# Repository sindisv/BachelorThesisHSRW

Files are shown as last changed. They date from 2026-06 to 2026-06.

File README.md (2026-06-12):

Thesis: Design and Development of a Cost-Effective Multi-Sensor Wearable System for Real-Time Biomechanical Analysis in Boxing

This repository contains the files and assets for the thesis. The top-level folders hold CAD models, electrical schematics, firmware, training data and a packaged software application. The application distributed with this repository is provided as a zip file.

Folder summary

* Software Arduino Sketches: Arduino/embedded firmware source code for the different device variants (sketch\_device1..4). Use the Arduino IDE or compatible toolchain to open and upload the .ino sketches to the target boards.
* Software Application: Packaged application for the project. The file My Application.zip contains the compiled application or installers/resources. Unzip the archive (for example with Explorer, 7-Zip, or unzip) and follow the included instructions or run the extracted executable where appropriate.
* CAD Files Fusion360: Fusion360 3D model files, STEP files and drawing exports. Subfolders separate 3D files and drawing sheets for each device/unit. These are used for enclosure and mechanical design.
* Electrical Schematics KiCad: KiCad schematic files for each device (Device 1..4) and custom symbols. Open these with KiCad to view or modify the electrical designs and generate PCBs.
* Training Sessions CSV and XLSX Files: CSV & XLSX datasets collected during training sessions. These contain recorded sensor data for specific motions and can be used for analysis, training models or evaluation.
* Software Machine Learning: python scripts for running, training and processing the machine learning.

Notes

* The repository does not currently include an installed application — the application is provided zipped under Software Application/My Application.zip. Extract that archive to access the application files.
* Inspect each folder for README or instruction files specific to that component (for example CAD export notes or KiCad project details).

Important files and expanded per-folder details

1. Software Arduino Sketches
* sketch\_device1/sketch\_device1.ino — firmware for device 1
* sketch\_device2/sketch\_device2.ino — firmware for device 2
* sketch\_device3/sketch\_device3.ino — firmware for device 3
* sketch\_device4/sketch\_device4.ino — firmware for device 4
Notes: open the appropriate .ino in the Arduino IDE or PlatformIO. Check board and library requirements in the top comments of each sketch (if present) before uploading.
2. Software Application

* My Application.zip (located in Software Application/) — packaged application bundle. Extract to view installers, binaries or resource files.

3. CAD Files Fusion360
* 3D Files Fusion360/ (contains .step STEP files for enclosures, batteries, PCB models and assembly files)
* Drawings Fusion360/ (contains .dwg and .pdf drawing exports for manufacturing and assembly)
Examples: "Enclosure Unit 1.step", "Assembly Unit 1.step", and the exported PDF drawings such as "Assembly Drawing and Parts List Unit 1.pdf".
Notes: STEP files can be opened in Fusion360, FreeCAD or other CAD tools. DWG files require a CAD viewer that supports AutoCAD formats.

4. Electrical Schematics KiCad
* Circuit Device 1.kicad\_sch
* Circuit Device 2.kicad\_sch
* Circuit Device 3 and Device 4.kicad\_sch
* XIAO\_Series\_SCH\_Symbols/.../Seeed\_Studio\_XIAO\_Series.kicad\_sym (custom symbols)
Notes: Open these in KiCad to inspect or export BOM/PCB layouts. Be aware of the KiCad version used to create the project if you encounter compatibility warnings.

5. Training Sessions CSV Files
* Training Sessions CSV Files/Session 2 (Specific Motions)/Device1.csv
* Device1Uppercut.csv, Device1hookfront.csv, Device3Jab.csv, Device3uppercut.csv, Boxinghookdevice3.csv
Notes: These CSV files contain recorded sensor traces from devices during motion sessions. They can be loaded into Python, MATLAB, or Excel for analysis and model training.

6. Software Machine Learning
There is a dedicated Machine Learning workspace under "Software Machine Learning/Software Machine Learning" and processed ML outputs under "Training Sessions CSV and XLSX Files/ml_complete". This area contains scripts to label data, extract features, train classifiers and produce evaluation outputs used in the thesis.
Important scripts (Software Machine Learning/Software Machine Learning):
 - label_boxing_data.py — helpers for labeling events/windows in raw sensor traces
 - preprocess.py — feature extraction and dataset assembly (produces ml_data/features_all.csv)
 - train_model.py — training pipeline: trains multiple classifiers, evaluates with cross-validation, generates plots and saves the best model
 - quick_analysis.py — small exploratory analysis and plotting utilities
 - boxing_analysis_complete6.py — more comprehensive analysis script used for experiments

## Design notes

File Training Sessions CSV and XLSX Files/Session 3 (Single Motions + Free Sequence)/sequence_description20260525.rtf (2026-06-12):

All sequences in orthodox stance (left side forward)

Sensor setup:
——————————

D1: left ankle
D2: right ankle
D3: left wrist
D4 right wrist

Sequences:
——————————

1a) Jabs (left arm straight punch)
1b) Cross (right arm straight punch)
1c) left hook
1d) right hook
1e) left uppercut
1f) right uppercut
— all in air, no impact on punching bag

2a) -2f) as 1), with impact on punching bag

3a) low kick left
3b) low kick right
3c) mid kick left
3d) mid kick right
3e) high kick left
3f) high kick right

— all with impact on punching bag

4a) front kick left
4b) front kick right
4c) side kick left
4d) side kick right
— all with impact on punching bag

5) validation round (free sequence, all with impact on punching bag

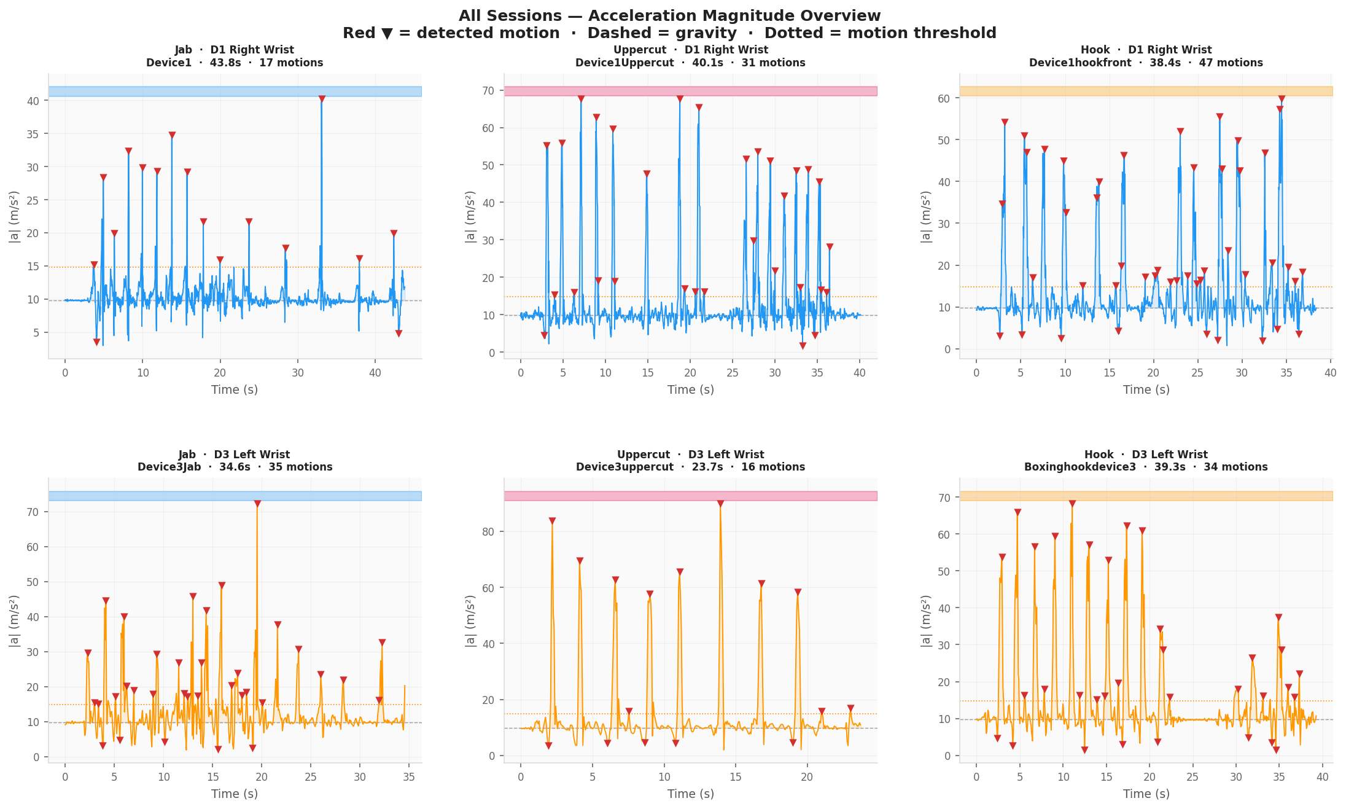
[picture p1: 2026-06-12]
Training Sessions CSV and XLSX Files/Session 2 (Specific Motions)/session2plots/overview_all_sessions.png

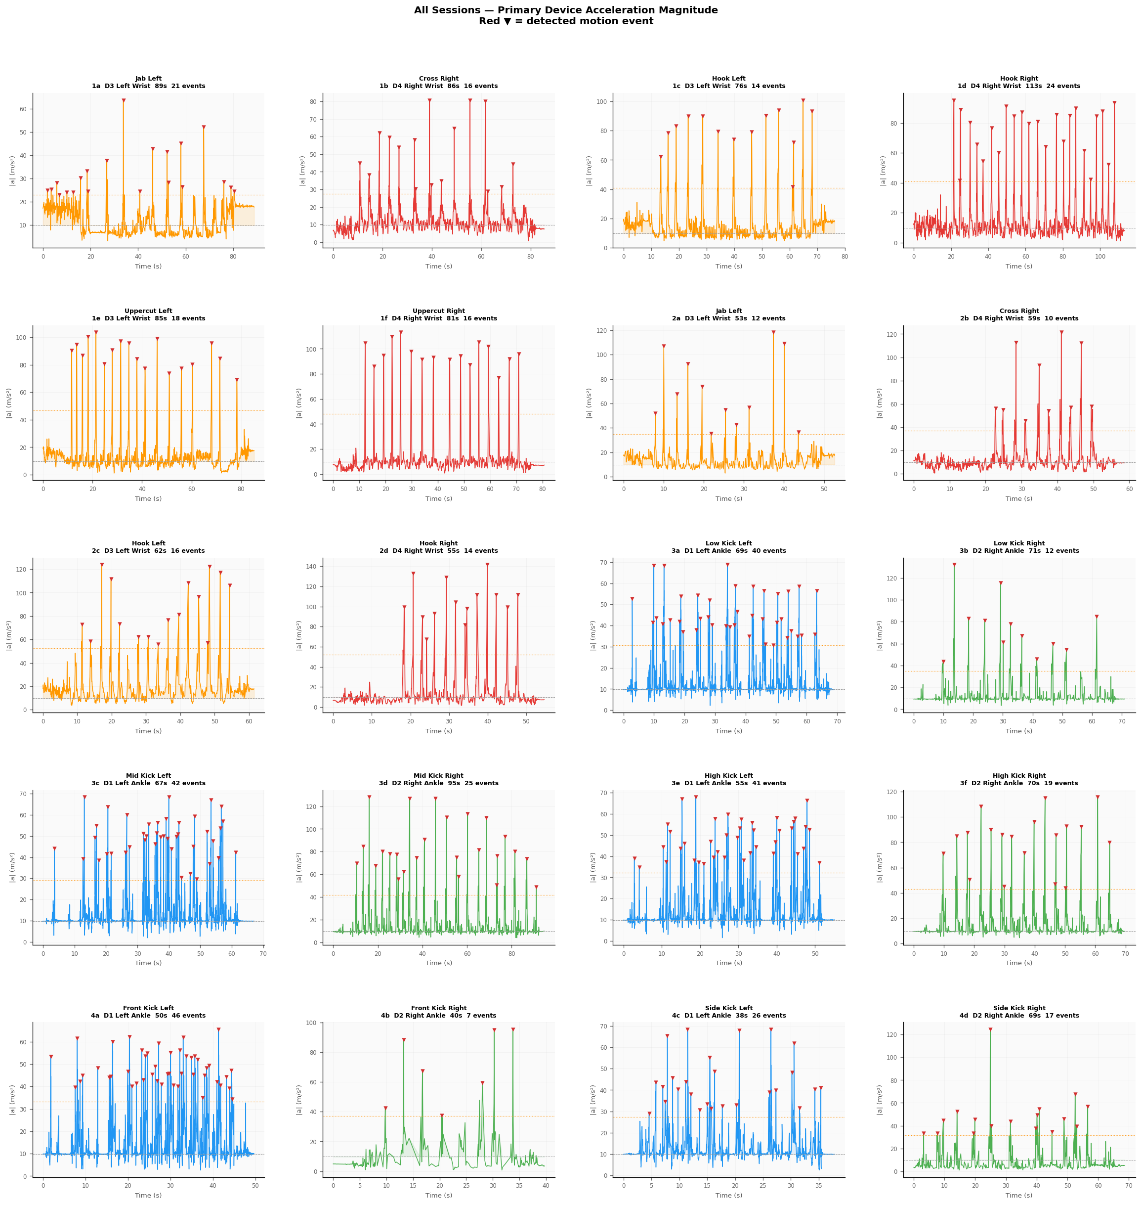
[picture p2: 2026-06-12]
Training Sessions CSV and XLSX Files/plots_complete/overview_all_sessions.png

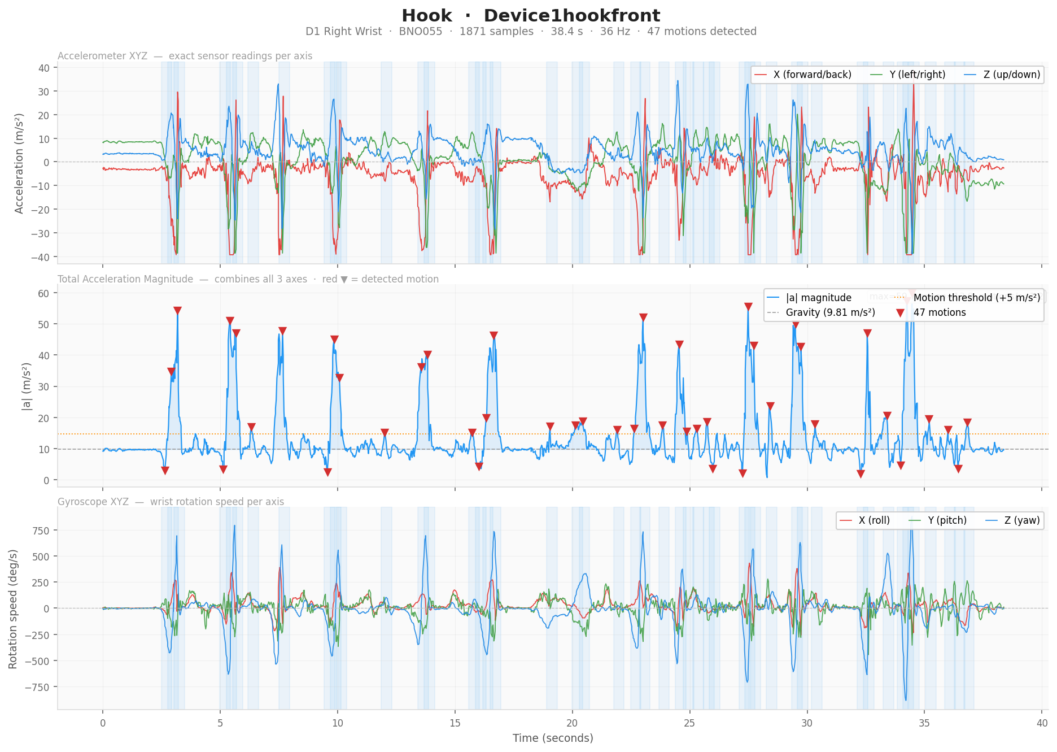
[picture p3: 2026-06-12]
Training Sessions CSV and XLSX Files/Session 2 (Specific Motions)/session2plots/Device1hookfront_analysis.png

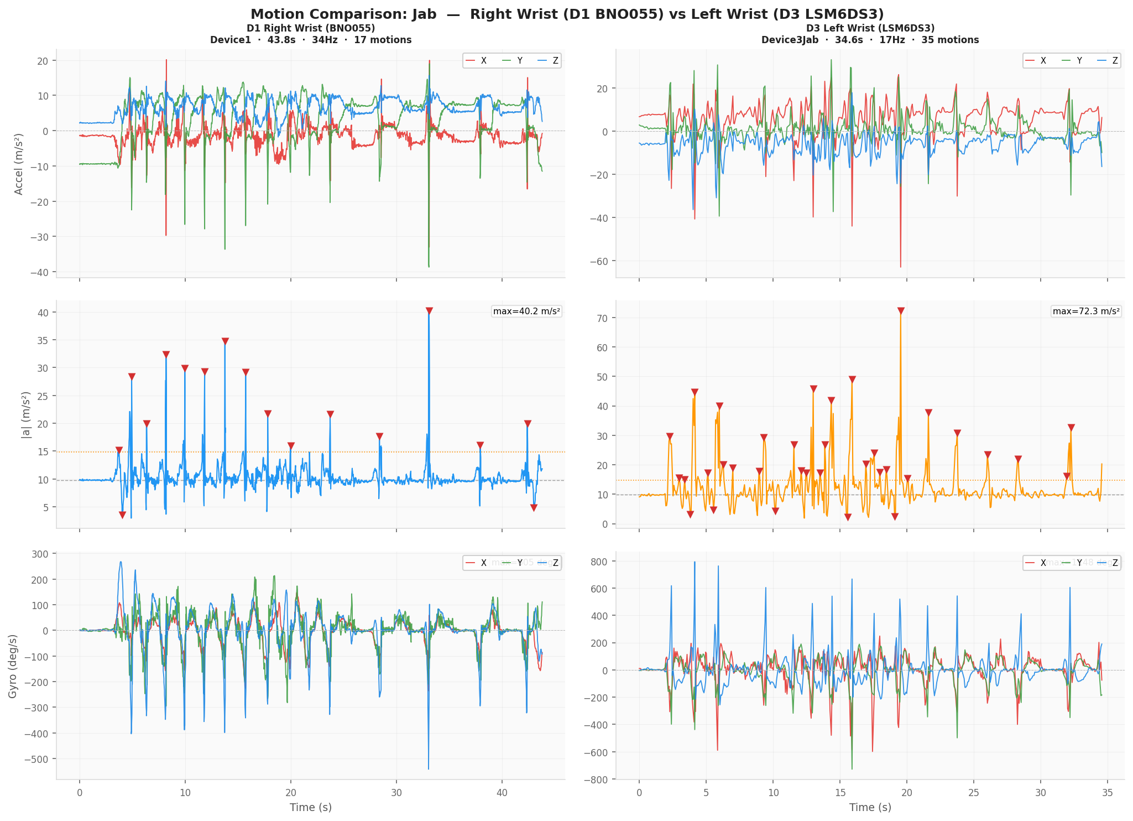
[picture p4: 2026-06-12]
Training Sessions CSV and XLSX Files/Session 2 (Specific Motions)/session2plots/comparisonofjabdevice1device3.png

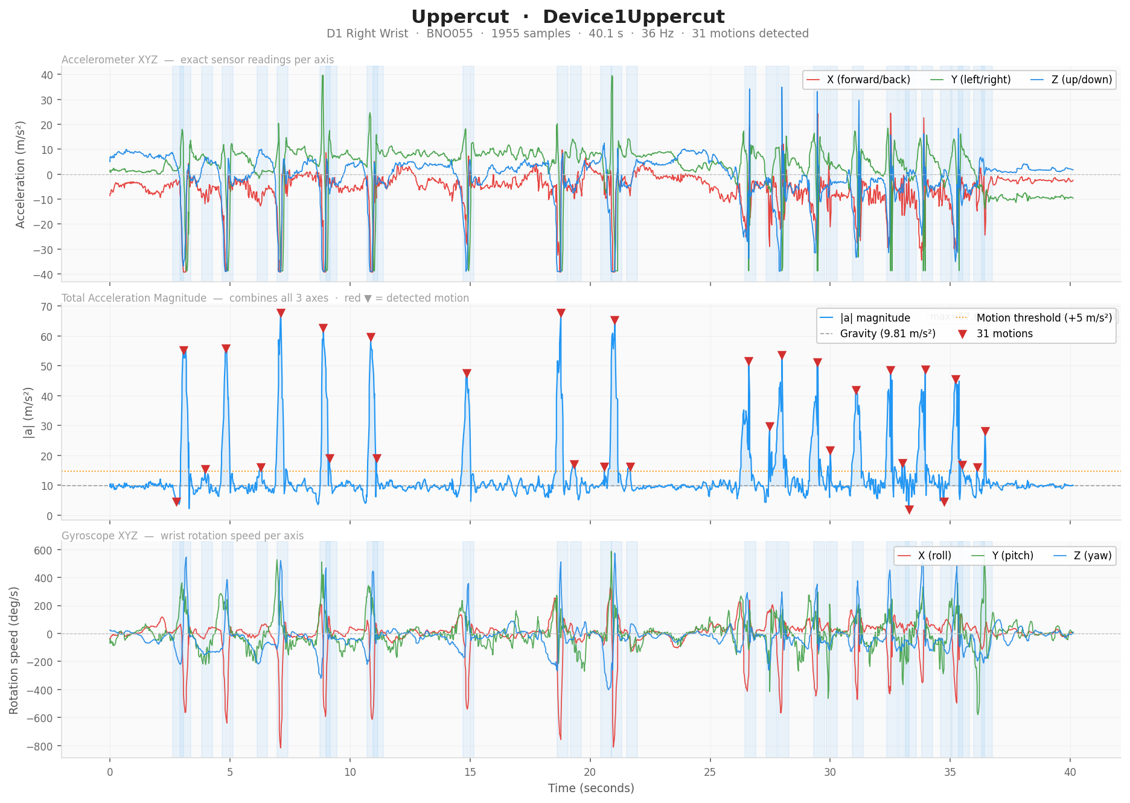
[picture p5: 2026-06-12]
Training Sessions CSV and XLSX Files/Session 2 (Specific Motions)/session2plots/Device1Uppercut_analysis.png

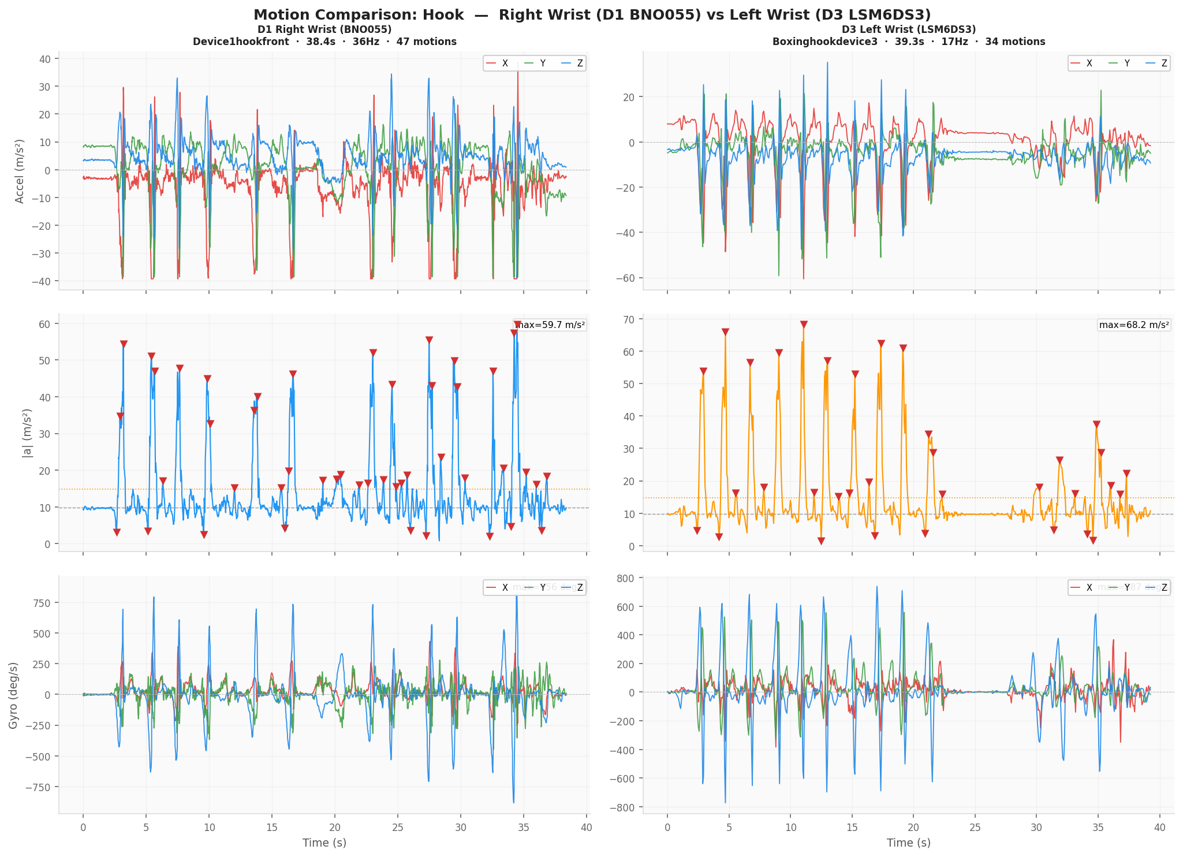
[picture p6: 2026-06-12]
Training Sessions CSV and XLSX Files/Session 2 (Specific Motions)/session2plots/compare_Hook.png

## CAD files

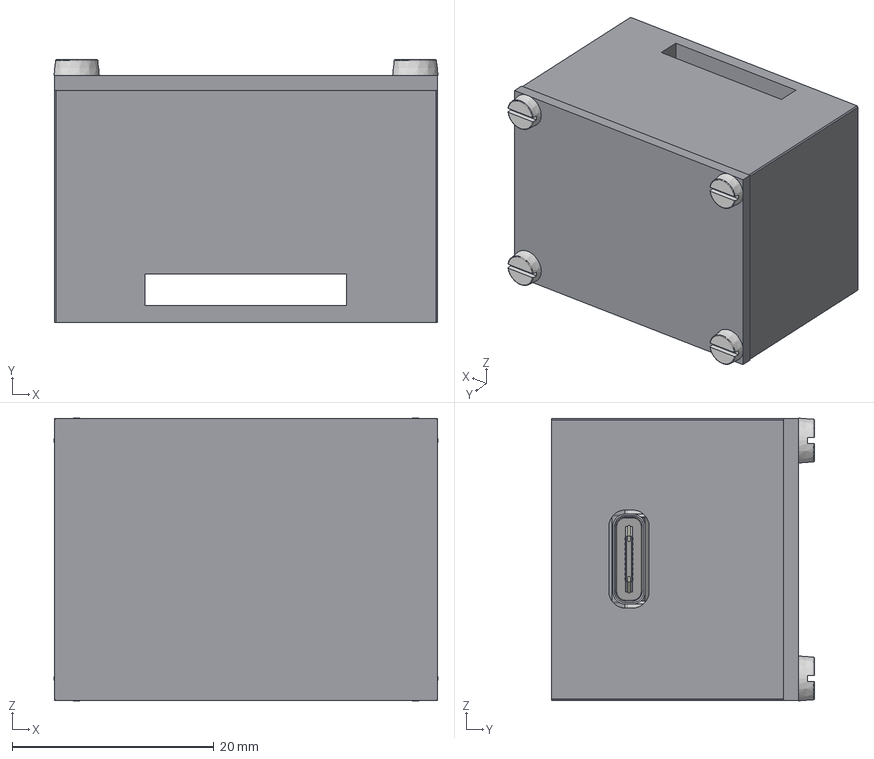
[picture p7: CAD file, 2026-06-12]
CAD Files Fusion360/3D Files Fusion360/Assemblies of the Units/Assembly Units 3 & 4.step
38.1 x 26.1 x 28.1 mm
BOSS-EXTRUDE14_8_
BOSS-EXTRUDE7_4_
BOSS-EXTRUDE7_3_
BOSS-EXTRUDE14_4_
BOSS-EXTRUDE14_2_
BOSS-EXTRUDE14_11_
BOSS-EXTRUDE7_7_
BOSS-EXTRUDE14_9_
BOSS-EXTRUDE14_3_
BOSS-EXTRUDE14_7_
MIRROR2
BOSS-EXTRUDE14_5_
BOSS-EXTRUDE14_12_
BOSS-EXTRUDE7_8_
BOSS-EXTRUDE7_1_
BOSS-EXTRUDE14_10_
BOSS-EXTRUDE7_9_
BOSS-EXTRUDE14_6_
BOSS-EXTRUDE14_1_
BOSS-EXTRUDE7_6_
BOSS-EXTRUDE7_2_
CUT-EXTRUDE5
BOSS-EXTRUDE7_5_
Shield
Pins
LiPo Battery 200 mAh
Enclosure Unit 3, 4
Enclosure Lid Unit 3,4
DIN 84 - M2.5 x 4 Steel 4.6 Plain x 4

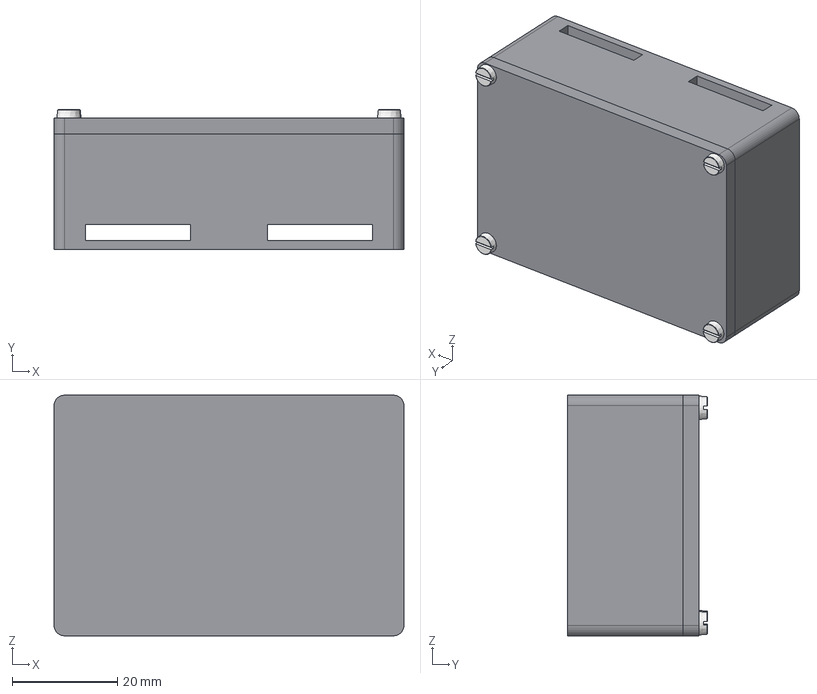
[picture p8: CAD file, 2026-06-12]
CAD Files Fusion360/3D Files Fusion360/Assemblies of the Units/Assembly Unit 1.step
66.6 x 26.6 x 45.8 mm
Prototyping Board
Adafruit_BNO055_AP214
BOSS-EXTRUDE14_8_
BOSS-EXTRUDE7_4_
BOSS-EXTRUDE7_3_
BOSS-EXTRUDE14_4_
BOSS-EXTRUDE14_2_
BOSS-EXTRUDE14_11_
BOSS-EXTRUDE7_7_
BOSS-EXTRUDE14_9_
BOSS-EXTRUDE14_3_
BOSS-EXTRUDE14_7_
MIRROR2
BOSS-EXTRUDE14_5_
BOSS-EXTRUDE14_12_
BOSS-EXTRUDE7_8_
BOSS-EXTRUDE7_1_
BOSS-EXTRUDE14_10_
BOSS-EXTRUDE7_9_
BOSS-EXTRUDE14_6_
BOSS-EXTRUDE14_1_
BOSS-EXTRUDE7_6_
BOSS-EXTRUDE7_2_
CUT-EXTRUDE5
BOSS-EXTRUDE7_5_
Shield
Pins
CAP x 2
ANT1
Silkscreen
CAP 3
LED
USR
MSM261D3526H1CPM
Enclosure Unit 1
Enclosure Lid Unit 1
DIN 84 - M2.5 x 4 Stainless Steel A2 Plain x 4
DIN 84 - M3 x 6 Stainless Steel A2 Plain x 2

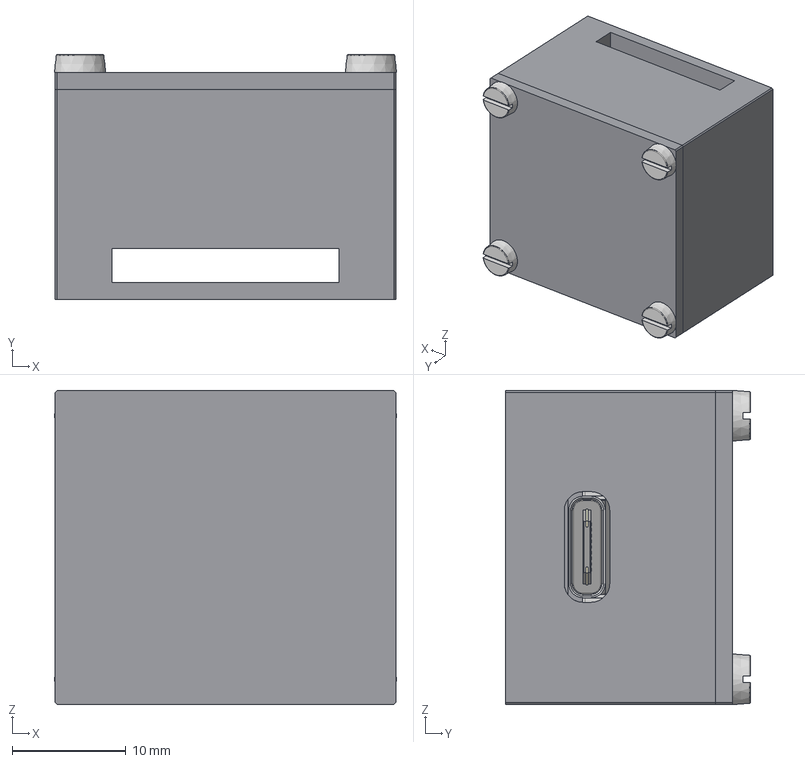
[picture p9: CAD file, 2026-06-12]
CAD Files Fusion360/3D Files Fusion360/Assemblies of the Units/Assembly Unit 2.step
30.1 x 21.6 x 27.7 mm
Li-Ion Battery 100mAh
BOSS-EXTRUDE14_8_
BOSS-EXTRUDE7_4_
BOSS-EXTRUDE7_3_
BOSS-EXTRUDE14_4_
BOSS-EXTRUDE14_2_
BOSS-EXTRUDE14_11_
BOSS-EXTRUDE7_7_
BOSS-EXTRUDE14_9_
BOSS-EXTRUDE14_3_
BOSS-EXTRUDE14_7_
MIRROR2
BOSS-EXTRUDE14_5_
BOSS-EXTRUDE14_12_
BOSS-EXTRUDE7_8_
BOSS-EXTRUDE7_1_
BOSS-EXTRUDE14_10_
BOSS-EXTRUDE7_9_
BOSS-EXTRUDE14_6_
BOSS-EXTRUDE14_1_
BOSS-EXTRUDE7_6_
BOSS-EXTRUDE7_2_
CUT-EXTRUDE5
BOSS-EXTRUDE7_5_
Shield
Pins
Enclosure Unit 2
Enclosure Lid Unit 2
DIN 84 - M2.5 x 4 Steel 4.6 Plain x 4

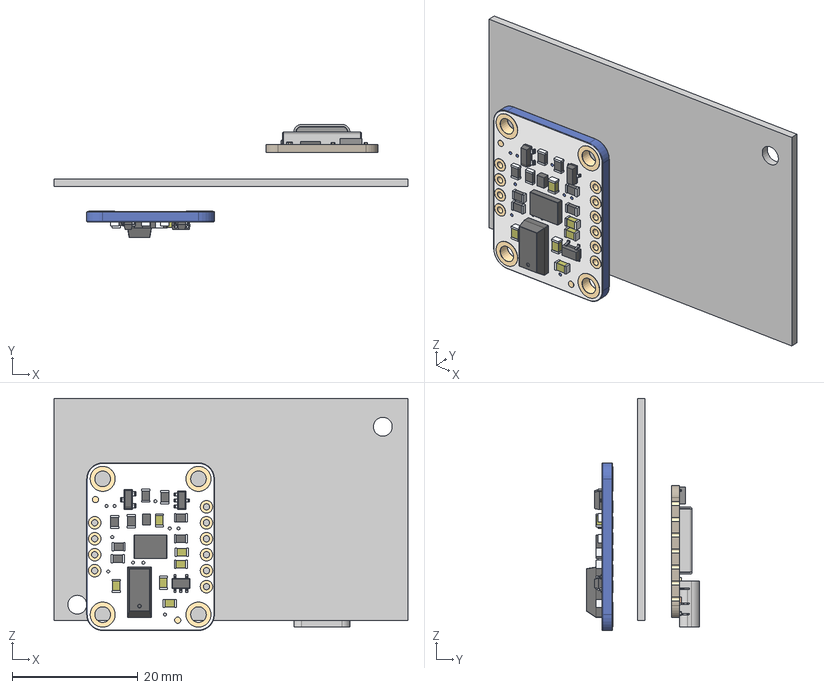
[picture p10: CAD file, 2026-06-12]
CAD Files Fusion360/3D Files Fusion360/Unit 1 Parts/Prototyping Board Assembly.step
56.3 x 18.0 x 36.9 mm
Prototyping Board
Adafruit_BNO055_AP214
BOSS-EXTRUDE14_8_
BOSS-EXTRUDE7_4_
BOSS-EXTRUDE7_3_
BOSS-EXTRUDE14_4_
BOSS-EXTRUDE14_2_
BOSS-EXTRUDE14_11_
BOSS-EXTRUDE7_7_
BOSS-EXTRUDE14_9_
BOSS-EXTRUDE14_3_
BOSS-EXTRUDE14_7_
MIRROR2
BOSS-EXTRUDE14_5_
BOSS-EXTRUDE14_12_
BOSS-EXTRUDE7_8_
BOSS-EXTRUDE7_1_
BOSS-EXTRUDE14_10_
BOSS-EXTRUDE7_9_
BOSS-EXTRUDE14_6_
BOSS-EXTRUDE14_1_
BOSS-EXTRUDE7_6_
BOSS-EXTRUDE7_2_
CUT-EXTRUDE5
BOSS-EXTRUDE7_5_
Shield
Pins
CAP x 2
ANT1
Silkscreen
CAP 3
LED
USR
MSM261D3526H1CPM

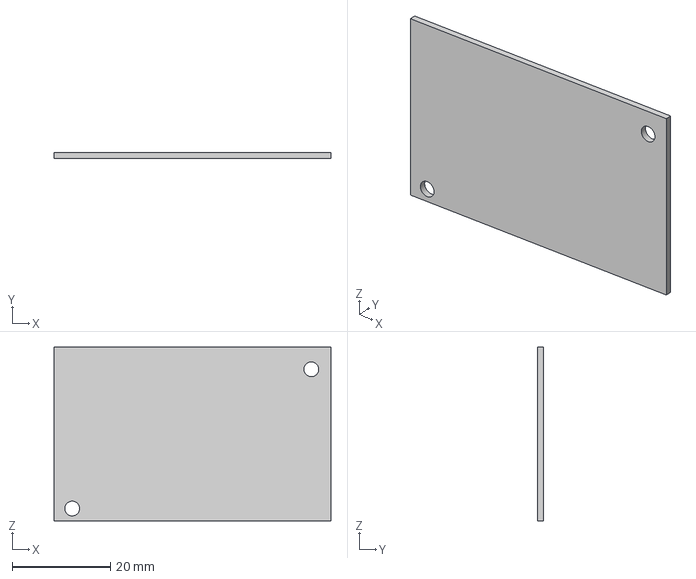
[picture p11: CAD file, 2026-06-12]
CAD Files Fusion360/3D Files Fusion360/Unit 1 Parts/Prototyping Board.step
56.3 x 1.20 x 35.3 mm

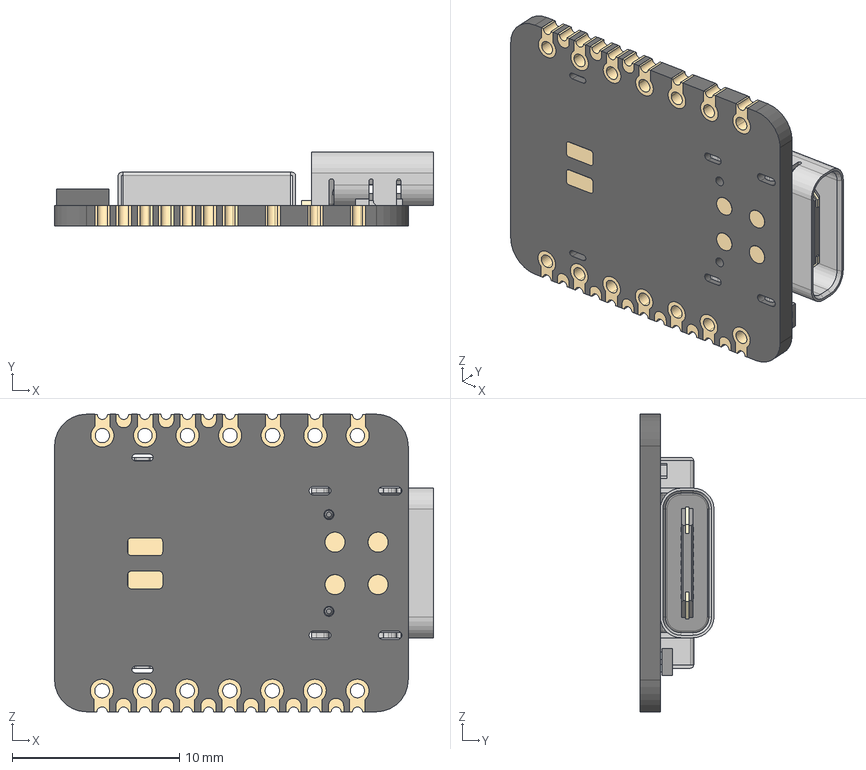
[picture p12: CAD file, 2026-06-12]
CAD Files Fusion360/3D Files Fusion360/Unit 2 Parts/XIAO nRF52840 Sense Plus v3.step
22.6 x 4.42 x 17.8 mm
BOSS-EXTRUDE14_8_
BOSS-EXTRUDE7_4_
BOSS-EXTRUDE7_3_
BOSS-EXTRUDE14_4_
BOSS-EXTRUDE14_2_
BOSS-EXTRUDE14_11_
BOSS-EXTRUDE7_7_
BOSS-EXTRUDE14_9_
BOSS-EXTRUDE14_3_
BOSS-EXTRUDE14_7_
MIRROR2
BOSS-EXTRUDE14_5_
BOSS-EXTRUDE14_12_
BOSS-EXTRUDE7_8_
BOSS-EXTRUDE7_1_
BOSS-EXTRUDE14_10_
BOSS-EXTRUDE7_9_
BOSS-EXTRUDE14_6_
BOSS-EXTRUDE14_1_
BOSS-EXTRUDE7_6_
BOSS-EXTRUDE7_2_
CUT-EXTRUDE5
BOSS-EXTRUDE7_5_
Shield
Pins

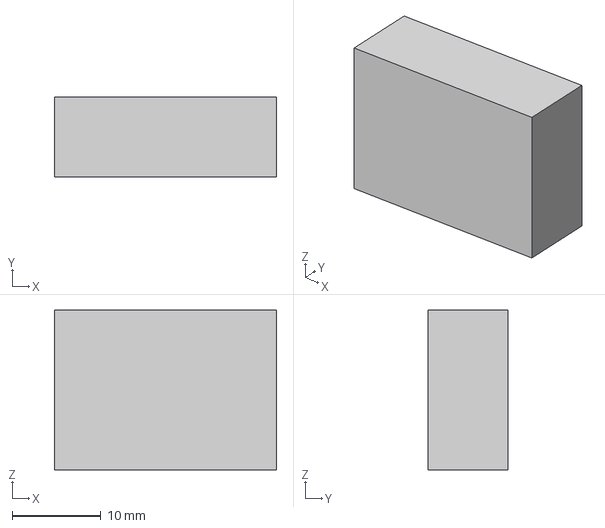
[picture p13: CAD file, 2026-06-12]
CAD Files Fusion360/3D Files Fusion360/Unit 3&4 Parts/LiPo Battery 200 mAh.step
25.0 x 9.00 x 18.0 mm

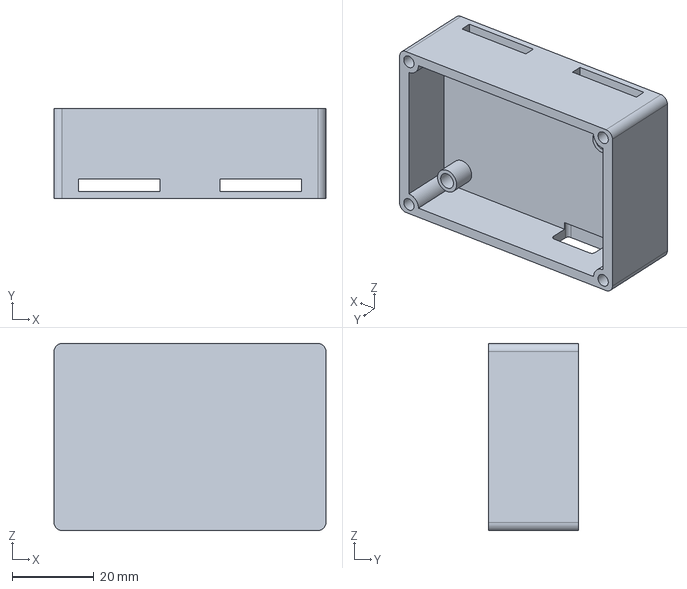
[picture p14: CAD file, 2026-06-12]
CAD Files Fusion360/3D Files Fusion360/Unit 1 Parts/Enclosure Unit 1.step
66.6 x 22.0 x 45.8 mm

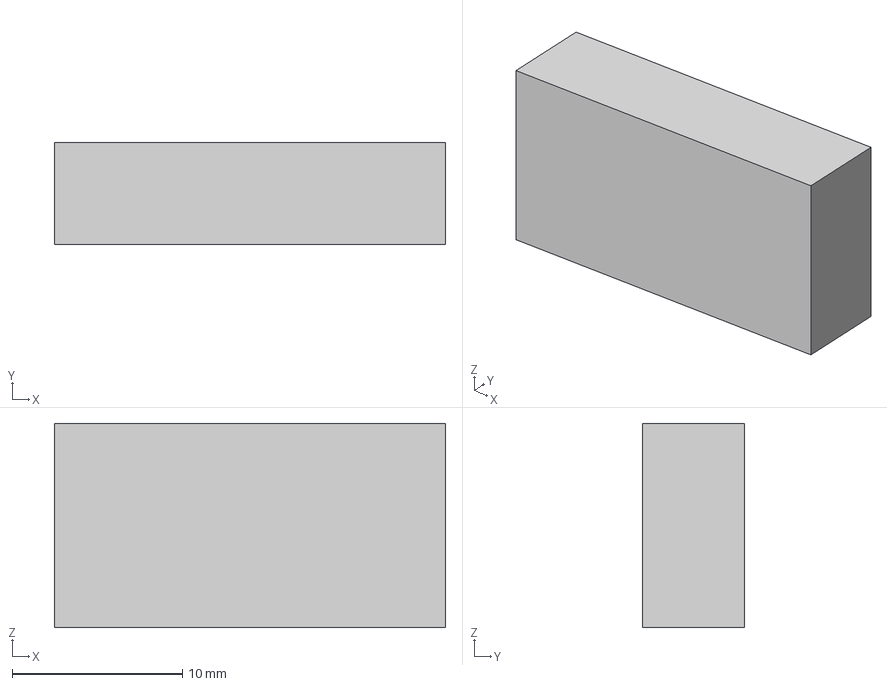
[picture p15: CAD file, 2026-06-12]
CAD Files Fusion360/3D Files Fusion360/Unit 2 Parts/Li-Ion Battery 100mAh.step
23.0 x 6.00 x 12.0 mm

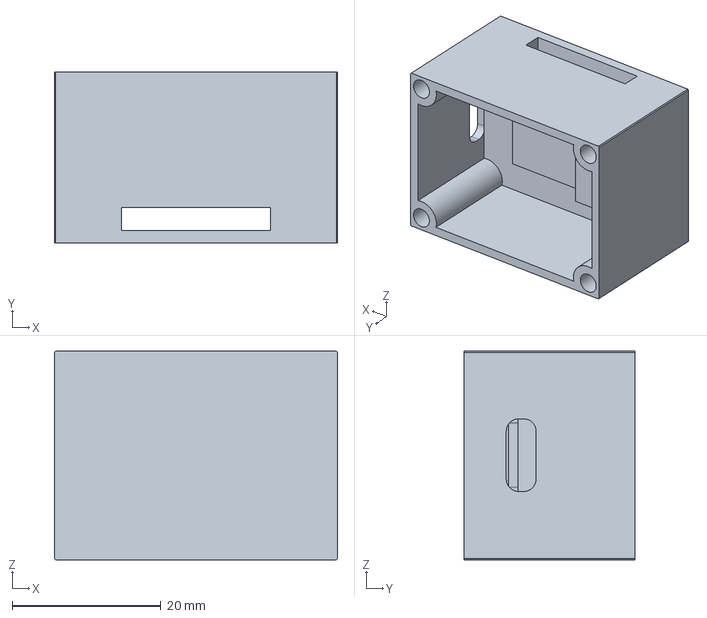
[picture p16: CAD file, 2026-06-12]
CAD Files Fusion360/3D Files Fusion360/Unit 3&4 Parts/Enclosure Unit 3, 4.step
38.0 x 23.0 x 28.0 mm

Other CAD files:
CAD Files Fusion360/Drawings Fusion360/Device No.2/Assembly Drawing and Parts List Unit 2.dwg
CAD Files Fusion360/Drawings Fusion360/Device No.3 and No.4/Assembly Drawing and Parts List Units 3&4.dwg
CAD Files Fusion360/Drawings Fusion360/Device No.1/Assembly Drawing and Parts List Unit 1.dwg
CAD Files Fusion360/3D Files Fusion360/Unit 3&4 Parts/Assembly Units 3 & 4.step
CAD Files Fusion360/Drawings Fusion360/Device No.1/Orthographic Drawing of the Lid for Unit 1.dwg
CAD Files Fusion360/Drawings Fusion360/Device No.1/Orthographic Drawing of the Enclosure for Unit 1.dwg
CAD Files Fusion360/Drawings Fusion360/Device No.2/Orthographic Drawing of the Enclosure for Unit 2.dwg
CAD Files Fusion360/Drawings Fusion360/Device No.3 and No.4/Orthographic Drawing of the Enclosure for Units 3&4.dwg
CAD Files Fusion360/3D Files Fusion360/Unit 1 Parts/Adafruit_BNO055_AP214.step
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

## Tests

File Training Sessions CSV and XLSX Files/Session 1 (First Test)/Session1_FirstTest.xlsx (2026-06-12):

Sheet: Summary
IMU Boxing Data — All Sessions & Devices
Session Name | Device | Location | Sensor Type | Rows | Duration (s) | Start | End
Session1Boxing | 1 | Dominant Wrist (Right Wrist) | BNO055 9-DOF | 455 | 47.5 | 2026-05-07 13:17:49.434000 | 2026-05-07 13:18:36.971000
Session1Boxing | 3 | Non-dominant Wrist (Left Wrist) | LSM6DS3 6-DOF built in Xiao nRF52840 Sense Plus | 502 | 47.5 | 2026-05-07 13:17:49.434000 | 2026-05-07 13:18:36.930000
Session2_4sensors | 1 | Dominant Wrist (Right Wrist) | BNO055 9-DOF | 793 | 82.9 | 2026-05-07 13:23:43.105000 | 2026-05-07 13:25:05.979000
Session2_4sensors | 2 | Right Ankle | LSM6DS3 6-DOF built in Xiao nRF52840 | 866 | 82.9 | 2026-05-07 13:23:43.105000 | 2026-05-07 13:25:05.978000
Session2_4sensors | 3 | Non-dominant Wrist (Left Wrist) | LSM6DS3 6-DOF built in Xiao nRF52840 Sense Plus | 888 | 82.9 | 2026-05-07 13:23:43.097000 | 2026-05-07 13:25:05.955000
Session2_4sensors | 4 | Left Ankle | LSM6DS3 6-DOF built in Xiao nRF52840 Sense Plus | 776 | 82.8 | 2026-05-07 13:23:43.107000 | 2026-05-07 13:25:05.947000
Session1Boxing | Device 1 and 3 used (look at table above) Set of motions: Jab, cross, hook, uppercut
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

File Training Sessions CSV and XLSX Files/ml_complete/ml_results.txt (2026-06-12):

Boxing ML Results
=================================================================

=================================================================
Task 1: Left vs Right Side
Classes: ['Left', 'Right']  Windows: 508  Baseline: 50.0%

  Random Forest: 99.6% ± 0.5%
              precision    recall  f1-score   support

        Left       1.00      0.99      1.00       304
       Right       0.99      1.00      1.00       204

    accuracy                           1.00       508
   macro avg       1.00      1.00      1.00       508
weighted avg       1.00      1.00      1.00       508

  SVM (RBF): 97.8% ± 1.7%
              precision    recall  f1-score   support

        Left       0.99      0.98      0.98       304
       Right       0.97      0.98      0.97       204

    accuracy                           0.98       508
   macro avg       0.98      0.98      0.98       508
weighted avg       0.98      0.98      0.98       508

  SVM (Linear): 95.3% ± 1.9%
              precision    recall  f1-score   support

        Left       0.95      0.97      0.96       304
       Right       0.95      0.93      0.94       204

    accuracy                           0.95       508
   macro avg       0.95      0.95      0.95       508
weighted avg       0.95      0.95      0.95       508

  Gradient Boosting: 97.4% ± 2.3%
              precision    recall  f1-score   support

        Left       0.98      0.98      0.98       304
       Right       0.97      0.97      0.97       204

    accuracy                           0.97       508
   macro avg       0.97      0.97      0.97       508
weighted avg       0.97      0.97      0.97       508

  KNN (k=5): 96.6% ± 2.8%
              precision    recall  f1-score   support

        Left       0.96      0.98      0.97       304
       Right       0.97      0.94      0.96       204

    accuracy                           0.97       508
   macro avg       0.97      0.96      0.96       508
weighted avg       0.97      0.97      0.97       508

  Logistic Regression: 96.3% ± 1.6%
              precision    recall  f1-score   support

        Left       0.96      0.97      0.97       304
       Right       0.96      0.95      0.95       204

    accuracy                           0.96       508
   macro avg       0.96      0.96      0.96       508
weighted avg       0.96      0.96      0.96       508

  Best: Random Forest (99.6%)

=================================================================
Task 2: Punch vs Kick
Classes: ['Kick', 'Punch']  Windows: 508  Baseline: 50.0%

  Random Forest: 100.0% ± 0.0%
              precision    recall  f1-score   support

        Kick       1.00      1.00      1.00       275
       Punch       1.00      1.00      1.00       233

    accuracy                           1.00       508
   macro avg       1.00      1.00      1.00       508
weighted avg       1.00      1.00      1.00       508

  SVM (RBF): 99.2% ± 0.7%
              precision    recall  f1-score   support

        Kick       1.00      0.99      0.99       275
       Punch       0.99      1.00      0.99       233

    accuracy                           0.99       508
   macro avg       0.99      0.99      0.99       508
weighted avg       0.99      0.99      0.99       508

  SVM (Linear): 99.4% ± 1.2%
              precision    recall  f1-score   support

        Kick       0.99      1.00      0.99       275
       Punch       1.00      0.99      0.99       233

    accuracy                           0.99       508
   macro avg       0.99      0.99      0.99       508
weighted avg       0.99      0.99      0.99       508

  Gradient Boosting: 98.8% ± 1.4%
              precision    recall  f1-score   support

        Kick       0.98      1.00      0.99       275
       Punch       1.00      0.98      0.99       233

    accuracy                           0.99       508
   macro avg       0.99      0.99      0.99       508
weighted avg       0.99      0.99      0.99       508

  KNN (k=5): 98.6% ± 1.3%
              precision    recall  f1-score   support

        Kick       0.99      0.98      0.99       275
       Punch       0.98      0.99      0.99       233

    accuracy                           0.99       508
   macro avg       0.99      0.99      0.99       508
weighted avg       0.99      0.99      0.99       508

  Logistic Regression: 98.6% ± 1.0%
              precision    recall  f1-score   support

        Kick       0.99      0.99      0.99       275
       Punch       0.98      0.99      0.99       233

    accuracy                           0.99       508
   macro avg       0.99      0.99      0.99       508
weighted avg       0.99      0.99      0.99       508

  Best: Random Forest (100.0%)

=================================================================
Task 3: Punch Type (Jab / Cross / Hook / Uppercut)
Classes: ['Cross', 'Hook', 'Jab', 'Uppercut']  Windows: 233  Baseline: 25.0%

  Random Forest: 93.1% ± 2.5%
              precision    recall  f1-score   support

       Cross       1.00      0.65      0.79        26
        Hook       0.95      0.95      0.95        91
         Jab       0.87      1.00      0.93        59
    Uppercut       0.96      0.96      0.96        57

    accuracy                           0.93       233
   macro avg       0.94      0.89      0.91       233
weighted avg       0.94      0.93      0.93       233

  SVM (RBF): 96.1% ± 1.6%
              precision    recall  f1-score   support

       Cross       0.95      0.77      0.85        26
        Hook       0.96      0.98      0.97        91
         Jab       0.94      0.98      0.96        59
    Uppercut       1.00      1.00      1.00        57

    accuracy                           0.96       233
   macro avg       0.96      0.93      0.94       233
weighted avg       0.96      0.96      0.96       233

  SVM (Linear): 95.3% ± 2.5%
              precision    recall  f1-score   support

       Cross       0.95      0.81      0.88        26
        Hook       0.95      0.98      0.96        91
         Jab       0.93      0.93      0.93        59
    Uppercut       0.98      1.00      0.99        57

    accuracy                           0.95       233
   macro avg       0.95      0.93      0.94       233
weighted avg       0.95      0.95      0.95       233

  Gradient Boosting: 93.1% ± 3.1%
              precision    recall  f1-score   support

       Cross       0.83      0.77      0.80        26
        Hook       0.91      0.95      0.92        91
         Jab       0.97      0.95      0.96        59
    Uppercut       0.98      0.96      0.97        57

    accuracy                           0.93       233
   macro avg       0.92      0.91      0.91       233
weighted avg       0.93      0.93      0.93       233

  KNN (k=5): 90.5% ± 3.0%
              precision    recall  f1-score   support

       Cross       0.86      0.69      0.77        26
        Hook       0.98      0.87      0.92        91
         Jab       0.89      0.97      0.93        59
    Uppercut       0.85      1.00      0.92        57

    accuracy                           0.91       233
   macro avg       0.89      0.88      0.88       233
weighted avg       0.91      0.91      0.90       233

  Logistic Regression: 96.1% ± 2.1%
              precision    recall  f1-score   support

       Cross       1.00      0.81      0.89        26
        Hook       0.99      0.98      0.98        91
         Jab       0.93      0.97      0.95        59
    Uppercut       0.93      1.00      0.97        57

    accuracy                           0.96       233
   macro avg       0.96      0.94      0.95       233
weighted avg       0.96      0.96      0.96       233

  Best: SVM (RBF) (96.1%)

=================================================================
Task 4: Air vs Bag Contact
Classes: ['Air', 'Bag']  Windows: 233  Baseline: 50.0%

  Random Forest: 91.0% ± 2.2%
              precision    recall  f1-score   support

         Air       0.90      0.99      0.94       181
         Bag       0.94      0.63      0.76        52

    accuracy                           0.91       233
   macro avg       0.92      0.81      0.85       233
weighted avg       0.91      0.91      0.90       233

  SVM (RBF): 96.6% ± 1.7%
              precision    recall  f1-score   support

         Air       0.97      0.99      0.98       181
         Bag       0.96      0.88      0.92        52

    accuracy                           0.97       233
   macro avg       0.96      0.94      0.95       233
weighted avg       0.97      0.97      0.97       233

  SVM (Linear): 92.7% ± 1.7%
              precision    recall  f1-score   support

         Air       0.96      0.94      0.95       181
         Bag       0.82      0.87      0.84        52

    accuracy                           0.93       233
   macro avg       0.89      0.91      0.90       233
weighted avg       0.93      0.93      0.93       233

  Gradient Boosting: 90.6% ± 5.0%
              precision    recall  f1-score   support

         Air       0.93      0.96      0.94       181
         Bag       0.83      0.73      0.78        52

    accuracy                           0.91       233
   macro avg       0.88      0.84      0.86       233
weighted avg       0.90      0.91      0.90       233

  KNN (k=5): 91.0% ± 3.2%
              precision    recall  f1-score   support

         Air       0.90      0.99      0.94       181
         Bag       0.97      0.62      0.75        52

    accuracy                           0.91       233
   macro avg       0.93      0.80      0.85       233
weighted avg       0.92      0.91      0.90       233

  Logistic Regression: 95.3% ± 2.8%
              precision    recall  f1-score   support

         Air       0.97      0.97      0.97       181
         Bag       0.89      0.90      0.90        52

    accuracy                           0.95       233
   macro avg       0.93      0.94      0.93       233
weighted avg       0.95      0.95      0.95       233

  Best: SVM (RBF) (96.6%)

=================================================================
Task 5: Kick Type (Low / Mid / High / Front / Side)
Classes: ['Front Kick', 'High Kick', 'Low Kick', 'Mid Kick', 'Side Kick']  Windows: 275  Baseline: 20.0%

  Random Forest: 83.6% ± 6.3%
              precision    recall  f1-score   support

  Front Kick       0.90      0.89      0.90        53
   High Kick       0.81      0.83      0.82        60
    Low Kick       0.90      0.69      0.78        52
    Mid Kick       0.74      0.81      0.77        67
   Side Kick       0.90      1.00      0.95        43

    accuracy                           0.84       275
   macro avg       0.85      0.84      0.84       275
weighted avg       0.84      0.84      0.84       275

  SVM (RBF): 76.4% ± 7.0%
              precision    recall  f1-score   support

  Front Kick       0.85      0.87      0.86        53
   High Kick       0.74      0.75      0.74        60
    Low Kick       0.88      0.73      0.80        52
    Mid Kick       0.64      0.72      0.68        67
   Side Kick       0.79      0.77      0.78        43

    accuracy                           0.76       275
   macro avg       0.78      0.77      0.77       275
weighted avg       0.77      0.76      0.77       275

  SVM (Linear): 69.8% ± 7.2%
              precision    recall  f1-score   support

  Front Kick       0.78      0.89      0.83        53
   High Kick       0.68      0.73      0.70        60
    Low Kick       0.65      0.71      0.68        52
    Mid Kick       0.63      0.57      0.60        67
   Side Kick       0.79      0.60      0.68        43

    accuracy                           0.70       275
   macro avg       0.71      0.70      0.70       275
weighted avg       0.70      0.70      0.70       275

  Gradient Boosting: 85.8% ± 5.1%
              precision    recall  f1-score   support

  Front Kick       0.88      0.79      0.83        53
   High Kick       0.87      0.87      0.87        60
    Low Kick       0.93      0.77      0.84        52
    Mid Kick       0.78      0.90      0.83        67
   Side Kick       0.89      0.98      0.93        43

    accuracy                           0.86       275
   macro avg       0.87      0.86      0.86       275
weighted avg       0.86      0.86      0.86       275

  KNN (k=5): 65.8% ± 6.2%
              precision    recall  f1-score   support

  Front Kick       0.66      0.81      0.73        53
   High Kick       0.56      0.78      0.65        60
    Low Kick       0.84      0.52      0.64        52
    Mid Kick       0.60      0.54      0.57        67
   Side Kick       0.82      0.65      0.73        43

    accuracy                           0.66       275
   macro avg       0.70      0.66      0.66       275
weighted avg       0.68      0.66      0.66       275

  Logistic Regression: 73.8% ± 10.1%
              precision    recall  f1-score   support

  Front Kick       0.75      0.85      0.80        53
   High Kick       0.73      0.68      0.71        60
    Low Kick       0.79      0.71      0.75        52
    Mid Kick       0.68      0.73      0.71        67
   Side Kick       0.78      0.72      0.75        43

    accuracy                           0.74       275
   macro avg       0.74      0.74      0.74       275
weighted avg       0.74      0.74      0.74       275

  Best: Gradient Boosting (85.8%)

=================================================================
Task 6: All Motions — 16 classes (primary sensor only)
Classes: ['Cross Right', 'Front Kick Left', 'Front Kick Right', 'High Kick Left', 'High Kick Right', 'Hook Left', 'Hook Right', 'Jab Left', 'Jab Right', 'Low Kick Left', 'Low Kick Right', 'Mid Kick Left', 'Mid Kick Right', 'Side Kick Left', 'Side Kick Right', 'Uppercut Left', 'Uppercut Right']  Windows: 508  Baseline: 5.9%

  Random Forest: 90.7% ± 3.1%
                  precision    recall  f1-score   support

     Cross Right       0.96      0.96      0.96        26
 Front Kick Left       0.93      0.93      0.93        46
Front Kick Right       1.00      0.57      0.73         7
  High Kick Left       0.78      0.85      0.81        41
 High Kick Right       0.89      0.89      0.89        19
       Hook Left       1.00      0.95      0.97        39
      Hook Right       0.98      0.94      0.96        52
        Jab Left       0.96      1.00      0.98        44
       Jab Right       1.00      1.00      1.00        15
   Low Kick Left       0.89      0.85      0.87        40
  Low Kick Right       0.75      0.25      0.38        12
   Mid Kick Left       0.80      0.76      0.78        42
  Mid Kick Right       0.70      0.92      0.79        25
  Side Kick Left       1.00      1.00      1.00        26
 Side Kick Right       0.85      1.00      0.92        17
   Uppercut Left       0.96      1.00      0.98        26
  Uppercut Right       0.97      1.00      0.98        31

        accuracy                           0.91       508
       macro avg       0.91      0.88      0.88       508
    weighted avg       0.91      0.91      0.90       508

  SVM (RBF): 83.1% ± 4.1%
                  precision    recall  f1-score   support

     Cross Right       0.96      0.92      0.94        26
 Front Kick Left       0.78      0.83      0.80        46
Front Kick Right       0.86      0.86      0.86         7
  High Kick Left       0.69      0.71      0.70        41
 High Kick Right       0.68      0.89      0.77        19
       Hook Left       0.90      0.90      0.90        39
      Hook Right       0.86      0.92      0.89        52
        Jab Left       0.96      0.98      0.97        44
       Jab Right       1.00      1.00      1.00        15
   Low Kick Left       0.89      0.78      0.83        40
  Low Kick Right       0.50      0.17      0.25        12
   Mid Kick Left       0.60      0.64      0.62        42
  Mid Kick Right       0.65      0.68      0.67        25
  Side Kick Left       0.83      0.73      0.78        26
 Side Kick Right       0.93      0.82      0.88        17
   Uppercut Left       1.00      1.00      1.00        26
  Uppercut Right       1.00      1.00      1.00        31

        accuracy                           0.83       508
       macro avg       0.83      0.81      0.81       508
    weighted avg       0.83      0.83      0.83       508

  SVM (Linear): 84.2% ± 3.9%
                  precision    recall  f1-score   support

     Cross Right       0.89      0.96      0.93        26
 Front Kick Left       0.81      0.83      0.82        46
Front Kick Right       0.75      0.86      0.80         7
  High Kick Left       0.64      0.66      0.65        41
 High Kick Right       0.79      1.00      0.88        19
       Hook Left       0.93      0.97      0.95        39
      Hook Right       1.00      0.92      0.96        52
        Jab Left       0.98      0.93      0.95        44
       Jab Right       1.00      1.00      1.00        15
   Low Kick Left       0.81      0.75      0.78        40
  Low Kick Right       0.55      0.50      0.52        12
   Mid Kick Left       0.65      0.71      0.68        42
  Mid Kick Right       0.74      0.68      0.71        25
  Side Kick Left       0.74      0.65      0.69        26
 Side Kick Right       0.93      0.82      0.88        17
   Uppercut Left       1.00      1.00      1.00        26
  Uppercut Right       0.97      1.00      0.98        31

        accuracy                           0.84       508
       macro avg       0.83      0.84      0.83       508
    weighted avg       0.84      0.84      0.84       508

  Gradient Boosting: 88.4% ± 1.4%
                  precision    recall  f1-score   support

     Cross Right       0.96      0.92      0.94        26
 Front Kick Left       0.88      0.91      0.89        46
Front Kick Right       0.67      0.57      0.62         7
  High Kick Left       0.79      0.83      0.81        41
 High Kick Right       0.94      0.84      0.89        19
       Hook Left       1.00      0.95      0.97        39
      Hook Right       0.84      0.92      0.88        52
        Jab Left       0.96      1.00      0.98        44
       Jab Right       1.00      1.00      1.00        15
   Low Kick Left       0.92      0.82      0.87        40
  Low Kick Right       0.73      0.67      0.70        12
   Mid Kick Left       0.76      0.76      0.76        42
  Mid Kick Right       0.81      0.84      0.82        25
  Side Kick Left       1.00      1.00      1.00        26
 Side Kick Right       0.83      0.88      0.86        17
   Uppercut Left       0.96      0.88      0.92        26
  Uppercut Right       0.87      0.87      0.87        31

        accuracy                           0.88       508
       macro avg       0.88      0.86      0.87       508
    weighted avg       0.89      0.88      0.88       508

  KNN (k=5): 77.0% ± 4.3%
                  precision    recall  f1-score   support

     Cross Right       0.92      0.88      0.90        26
 Front Kick Left       0.63      0.85      0.72        46
Front Kick Right       0.80      0.57      0.67         7
  High Kick Left       0.61      0.73      0.67        41
 High Kick Right       0.53      0.89      0.67        19
       Hook Left       0.94      0.79      0.86        39
      Hook Right       1.00      0.85      0.92        52
        Jab Left       0.88      0.95      0.91        44
       Jab Right       0.94      1.00      0.97        15
   Low Kick Left       0.89      0.62      0.74        40
  Low Kick Right       1.00      0.17      0.29        12
   Mid Kick Left       0.59      0.55      0.57        42
  Mid Kick Right       0.63      0.48      0.55        25
  Side Kick Left       0.76      0.50      0.60        26
 Side Kick Right       0.61      0.82      0.70        17
   Uppercut Left       0.87      1.00      0.93        26
  Uppercut Right       0.86      1.00      0.93        31

        accuracy                           0.77       508
       macro avg       0.79      0.75      0.74       508
    weighted avg       0.79      0.77      0.76       508

  Logistic Regression: 84.0% ± 4.8%
                  precision    recall  f1-score   support

     Cross Right       0.96      0.96      0.96        26
 Front Kick Left       0.77      0.80      0.79        46
Front Kick Right       0.75      0.86      0.80         7
  High Kick Left       0.72      0.71      0.72        41
 High Kick Right       0.86      0.95      0.90        19
       Hook Left       0.88      0.95      0.91        39
      Hook Right       0.98      0.90      0.94        52
        Jab Left       0.98      0.93      0.95        44
       Jab Right       0.88      1.00      0.94        15
   Low Kick Left       0.79      0.78      0.78        40
  Low Kick Right       0.58      0.58      0.58        12
   Mid Kick Left       0.66      0.64      0.65        42
  Mid Kick Right       0.79      0.76      0.78        25
  Side Kick Left       0.63      0.65      0.64        26
 Side Kick Right       0.93      0.82      0.88        17
   Uppercut Left       1.00      1.00      1.00        26
  Uppercut Right       0.97      1.00      0.98        31

        accuracy                           0.84       508
       macro avg       0.83      0.84      0.84       508
    weighted avg       0.84      0.84      0.84       508

  Best: Random Forest (90.7%)

=================================================================
Task 7: All Motions — multi-sensor (thesis accuracy)
Classes: ['Cross Right', 'Front Kick Left', 'Front Kick Right', 'High Kick Left', 'High Kick Right', 'Hook Left', 'Hook Right', 'Jab Left', 'Jab Right', 'Low Kick Left', 'Low Kick Right', 'Mid Kick Left', 'Mid Kick Right', 'Side Kick Left', 'Side Kick Right', 'Uppercut Left', 'Uppercut Right']  Windows: 508  Baseline: 5.9%

  Random Forest: 99.2% ± 0.4%
                  precision    recall  f1-score   support

     Cross Right       0.96      1.00      0.98        26
 Front Kick Left       1.00      1.00      1.00        46
Front Kick Right       1.00      1.00      1.00         7
  High Kick Left       1.00      0.98      0.99        41
 High Kick Right       1.00      1.00      1.00        19
       Hook Left       1.00      0.97      0.99        39
      Hook Right       0.98      0.98      0.98        52
        Jab Left       0.98      1.00      0.99        44
       Jab Right       1.00      0.93      0.97        15
   Low Kick Left       1.00      1.00      1.00        40
  Low Kick Right       1.00      1.00      1.00        12
   Mid Kick Left       0.98      1.00      0.99        42
  Mid Kick Right       1.00      1.00      1.00        25
  Side Kick Left       1.00      1.00      1.00        26
 Side Kick Right       1.00      1.00      1.00        17
   Uppercut Left       1.00      1.00      1.00        26
  Uppercut Right       1.00      1.00      1.00        31

        accuracy                           0.99       508
       macro avg       0.99      0.99      0.99       508
    weighted avg       0.99      0.99      0.99       508

  SVM (RBF): 92.3% ± 1.6%
                  precision    recall  f1-score   support
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

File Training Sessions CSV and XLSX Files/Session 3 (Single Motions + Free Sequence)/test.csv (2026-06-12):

session_name | device_id | body_location | device_ts_ms | wall_clock_ms | accel_x | accel_y | accel_z | gyro_x | gyro_y | gyro_z | quat_w | quat_x | quat_y | quat_z
test | 1 | Left Ankle | 2636478 | 1779739046923 | 1.19 | 9.51 | 2.54 | 0.75 | 0.5 | 0.5 | 0.74560547 | 0.604126 | 0.11987305 | 0.2545166
test | 3 | Left Wrist | 8872206 | 1779739046923 | 7.5088787 | 5.9775677 | 5.304888 | 2.7757764 | -8.070301 | 44.13922 | 44.738907 | -39.354725 | 8.713265 | 0.0
test | 4 | Right Wrist | 35075158 | 1779739046947 | -1.3885354 | -4.079863 | -7.3316083 | -6.99496 | 0.91111183 | 1.623728 | -134.94055 | -19.62936 | 133.14279 | 0.0
test | 1 | Left Ankle | 2636494 | 1779739046947 | 1.2 | 9.52 | 2.49 | 0.5625 | 0.1875 | 0.625 | 0.7454834 | 0.604187 | 0.11981201 | 0.25457764
test | 2 | Right Ankle | 2364902 | 1779739046949 | -1.4927813 | -3.8285377 | 1.3160526 | -0.37282053 | -0.38065767 | -0.106820196 | -71.00352 | 20.232077 | 168.65182 | 0.0
test | 1 | Left Ankle | 2636519 | 1779739046949 | 1.21 | 9.53 | 2.51 | 0.4375 | 0.375 | 0.75 | 0.7454834 | 0.604187 | 0.11981201 | 0.25463867
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

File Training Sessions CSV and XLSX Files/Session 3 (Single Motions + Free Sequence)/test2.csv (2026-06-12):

session_name | device_id | body_location | device_ts_ms | wall_clock_ms | accel_x | accel_y | accel_z | gyro_x | gyro_y | gyro_z | quat_w | quat_x | quat_y | quat_z
test2 | 1 | Left Ankle | 2672859 | 1779739083306 | 1.09 | 9.5 | 2.44 | 0.4375 | 2.5 | 1.5625 | 0.7467041 | 0.5956421 | 0.12554932 | 0.26800537
test2 | 4 | Right Wrist | 35111519 | 1779739083306 | -1.5608186 | -5.907979 | -6.9391856 | -10.91496 | 11.621112 | 10.513728 | -144.68878 | 9.88668 | 132.52513 | 0.0
test2 | 3 | Left Wrist | 8908596 | 1779739083330 | 7.86541 | 7.0280166 | 4.981857 | -0.65422356 | -8.7003 | 44.97922 | 53.11448 | -41.638447 | 6.994011 | 0.0
test2 | 1 | Left Ankle | 2672882 | 1779739083333 | 1.5 | 9.34 | 2.62 | 1.375 | 4.375 | 2.6875 | 0.7463989 | 0.5956421 | 0.12591553 | 0.2687378
test2 | 1 | Left Ankle | 2672904 | 1779739083333 | 1.43 | 9.35 | 2.62 | 0.1875 | 0.875 | 2.6875 | 0.7461548 | 0.5957031 | 0.12585449 | 0.26934814
test2 | 2 | Right Ankle | 2401292 | 1779739083341 | -1.4664602 | -3.8740013 | 1.3758731 | 1.3771794 | -0.1006577 | -0.4568202 | -70.20288 | 19.573027 | 168.91942 | 0.0
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

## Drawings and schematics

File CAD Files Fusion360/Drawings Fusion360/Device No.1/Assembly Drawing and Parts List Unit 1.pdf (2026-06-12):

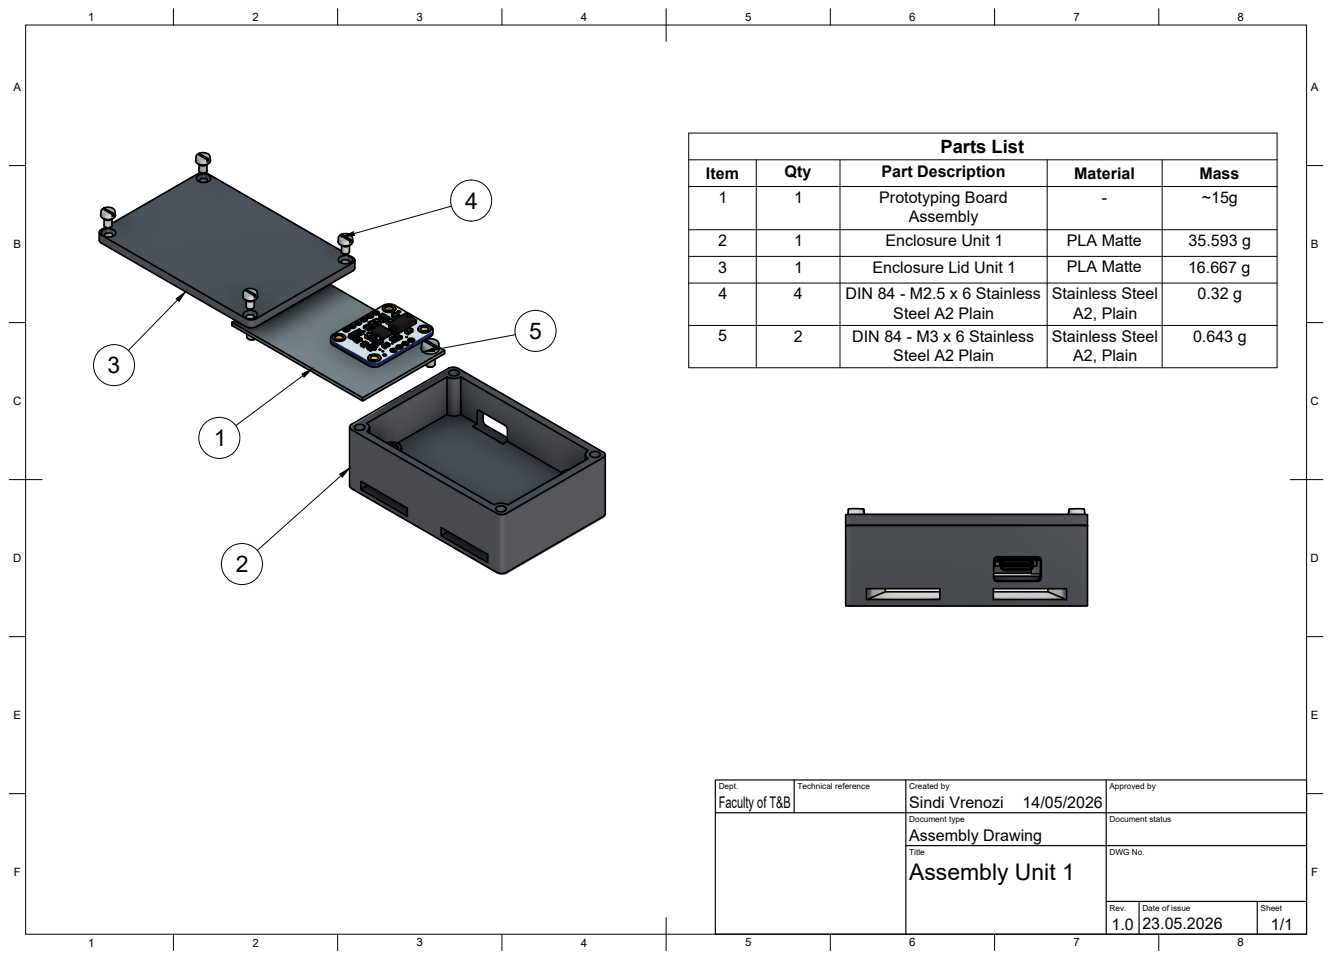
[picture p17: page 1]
Title; DWG No.; Rev.; Date of issue; Sheet; Assembly Unit 1; Parts List

Item | Qty | Part Description | Material | Mass
1 | 1 | Prototyping Board Assembly | - ~15g

2 | 1 | Enclosure Unit 1 | PLA Matte | 35.593 g
3 | 1 | Enclosure Lid Unit 1 | PLA Matte | 16.667 g
4 | 4 | DIN 84 - M2.5 x 6 Stainless Steel A2 Plain | Stainless Steel A2, Plain | 0.32 g

5 | 2 | DIN 84 - M3 x 6 Stainless Steel A2 Plain | Stainless Steel A2, Plain | 0.643 g

Dept. Faculty of T&B | Technical reference | Created by Sindi Vrenozi 14/05/2026 | Approved by

Document type Assembly Drawing | Document status

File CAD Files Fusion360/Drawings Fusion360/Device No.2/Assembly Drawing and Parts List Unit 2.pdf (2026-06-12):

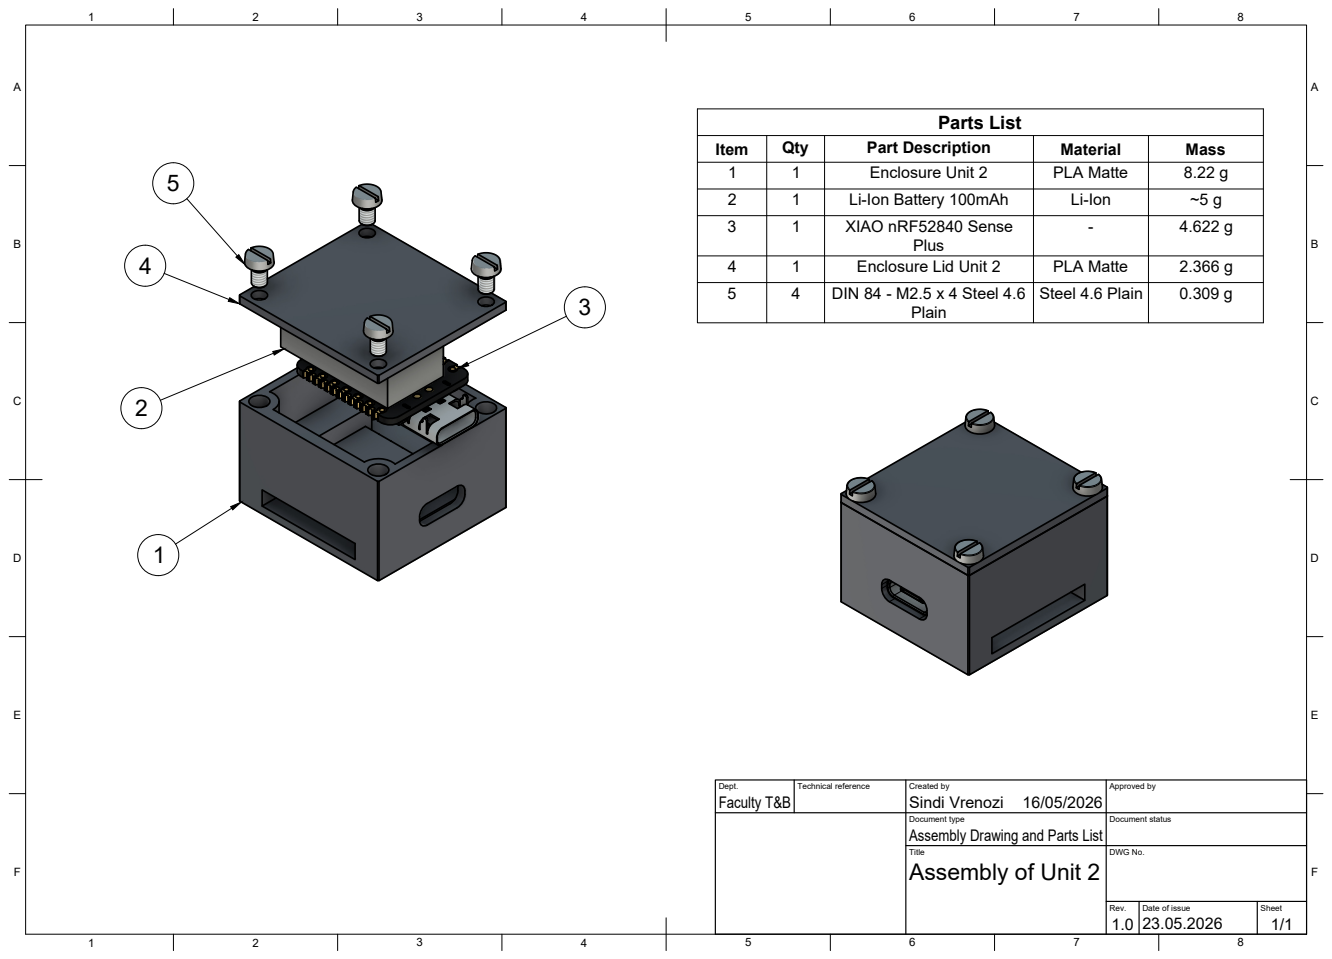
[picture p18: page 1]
Title; DWG No.; Rev.; Date of issue; Sheet; Parts List

Item | Qty | Part Description | Material | Mass
1 | 1 | Enclosure Unit 2 | PLA Matte | 8.22 g
2 | 1 | Li-Ion Battery 100mAh | Li-Ion | ~5 g
3 | 1 | XIAO nRF52840 Sense Plus | - 4.622 g

4 | 1 | Enclosure Lid Unit 2 | PLA Matte | 2.366 g
5 | 4 | DIN 84 - M2.5 x 4 Steel 4.6 Plain | Steel 4.6 Plain | 0.309 g

Dept. Faculty T&B | Technical reference | Created by Sindi Vrenozi 16/05/2026 | Approved by

Document type Assembly Drawing and Parts List | Document status

Assembly of Unit 2

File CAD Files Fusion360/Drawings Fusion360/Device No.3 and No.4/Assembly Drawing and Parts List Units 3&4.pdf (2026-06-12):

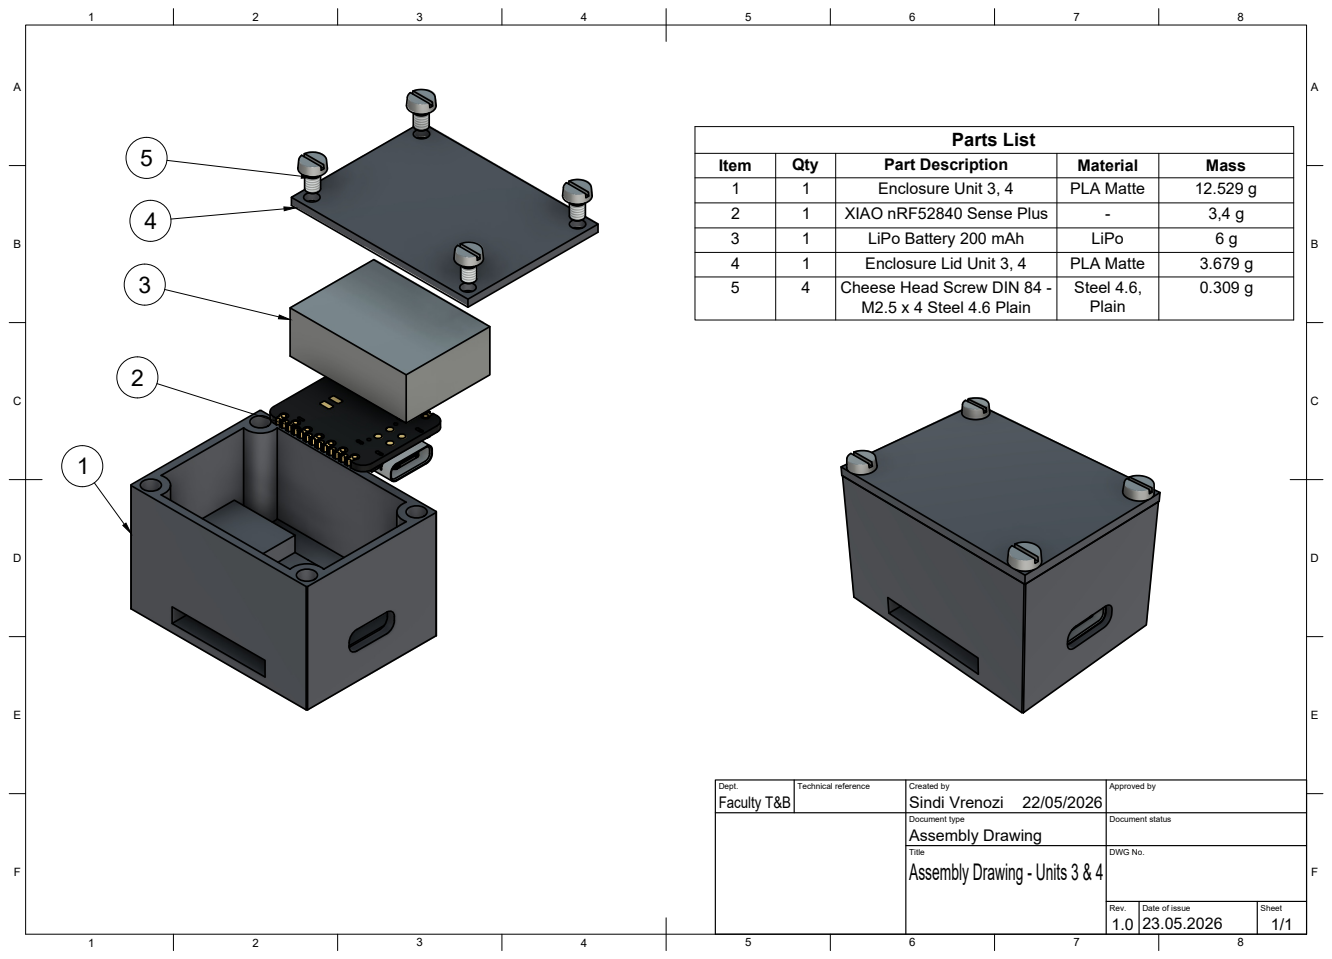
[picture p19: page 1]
Title; DWG No.; Rev.; Date of issue; Sheet; Parts List

Item | Qty | Part Description | Material | Mass
1 | 1 | Enclosure Unit 3, 4 | PLA Matte | 12.529 g
2 | 1 | XIAO nRF52840 Sense Plus | - | 3,4 g
3 | 1 | LiPo Battery 200 mAh | LiPo | 6 g
4 | 1 | Enclosure Lid Unit 3, 4 | PLA Matte | 3.679 g
5 | 4 | Cheese Head Screw DIN 84 -M2.5 x 4 Steel 4.6 Plain | Steel 4.6, Plain | 0.309 g

Dept. Faculty T&B | Technical reference | Created by Sindi Vrenozi 22/05/2026 | Approved by

Document type Assembly Drawing | Document status

Assembly Drawing - Units 3 & 4

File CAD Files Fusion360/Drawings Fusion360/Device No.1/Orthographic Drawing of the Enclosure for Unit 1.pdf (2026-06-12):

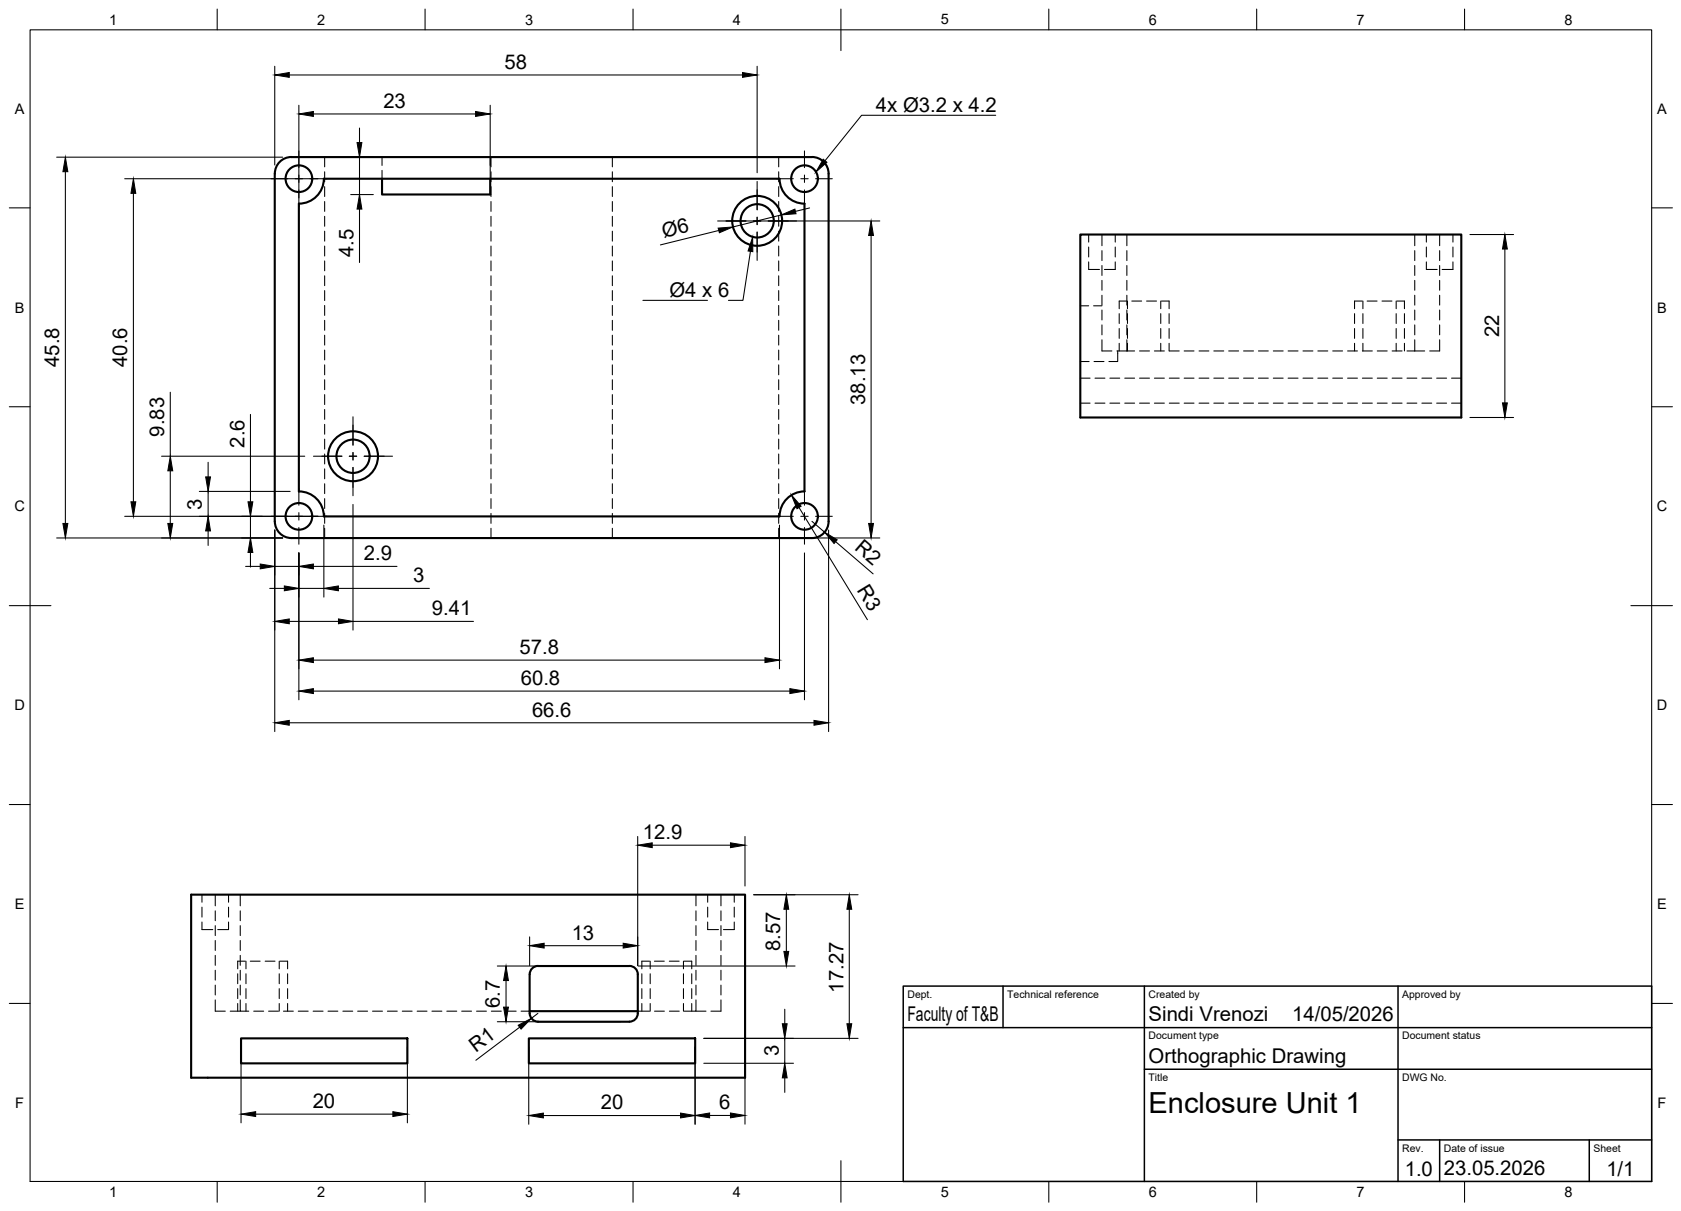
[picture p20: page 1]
Title; DWG No.; Rev.; Date of issue; Sheet; Enclosure Unit 1

Dept. Faculty of T&B | Technical reference | Created by Sindi Vrenozi 14/05/2026 | Approved by

Document type Orthographic Drawing | Document status

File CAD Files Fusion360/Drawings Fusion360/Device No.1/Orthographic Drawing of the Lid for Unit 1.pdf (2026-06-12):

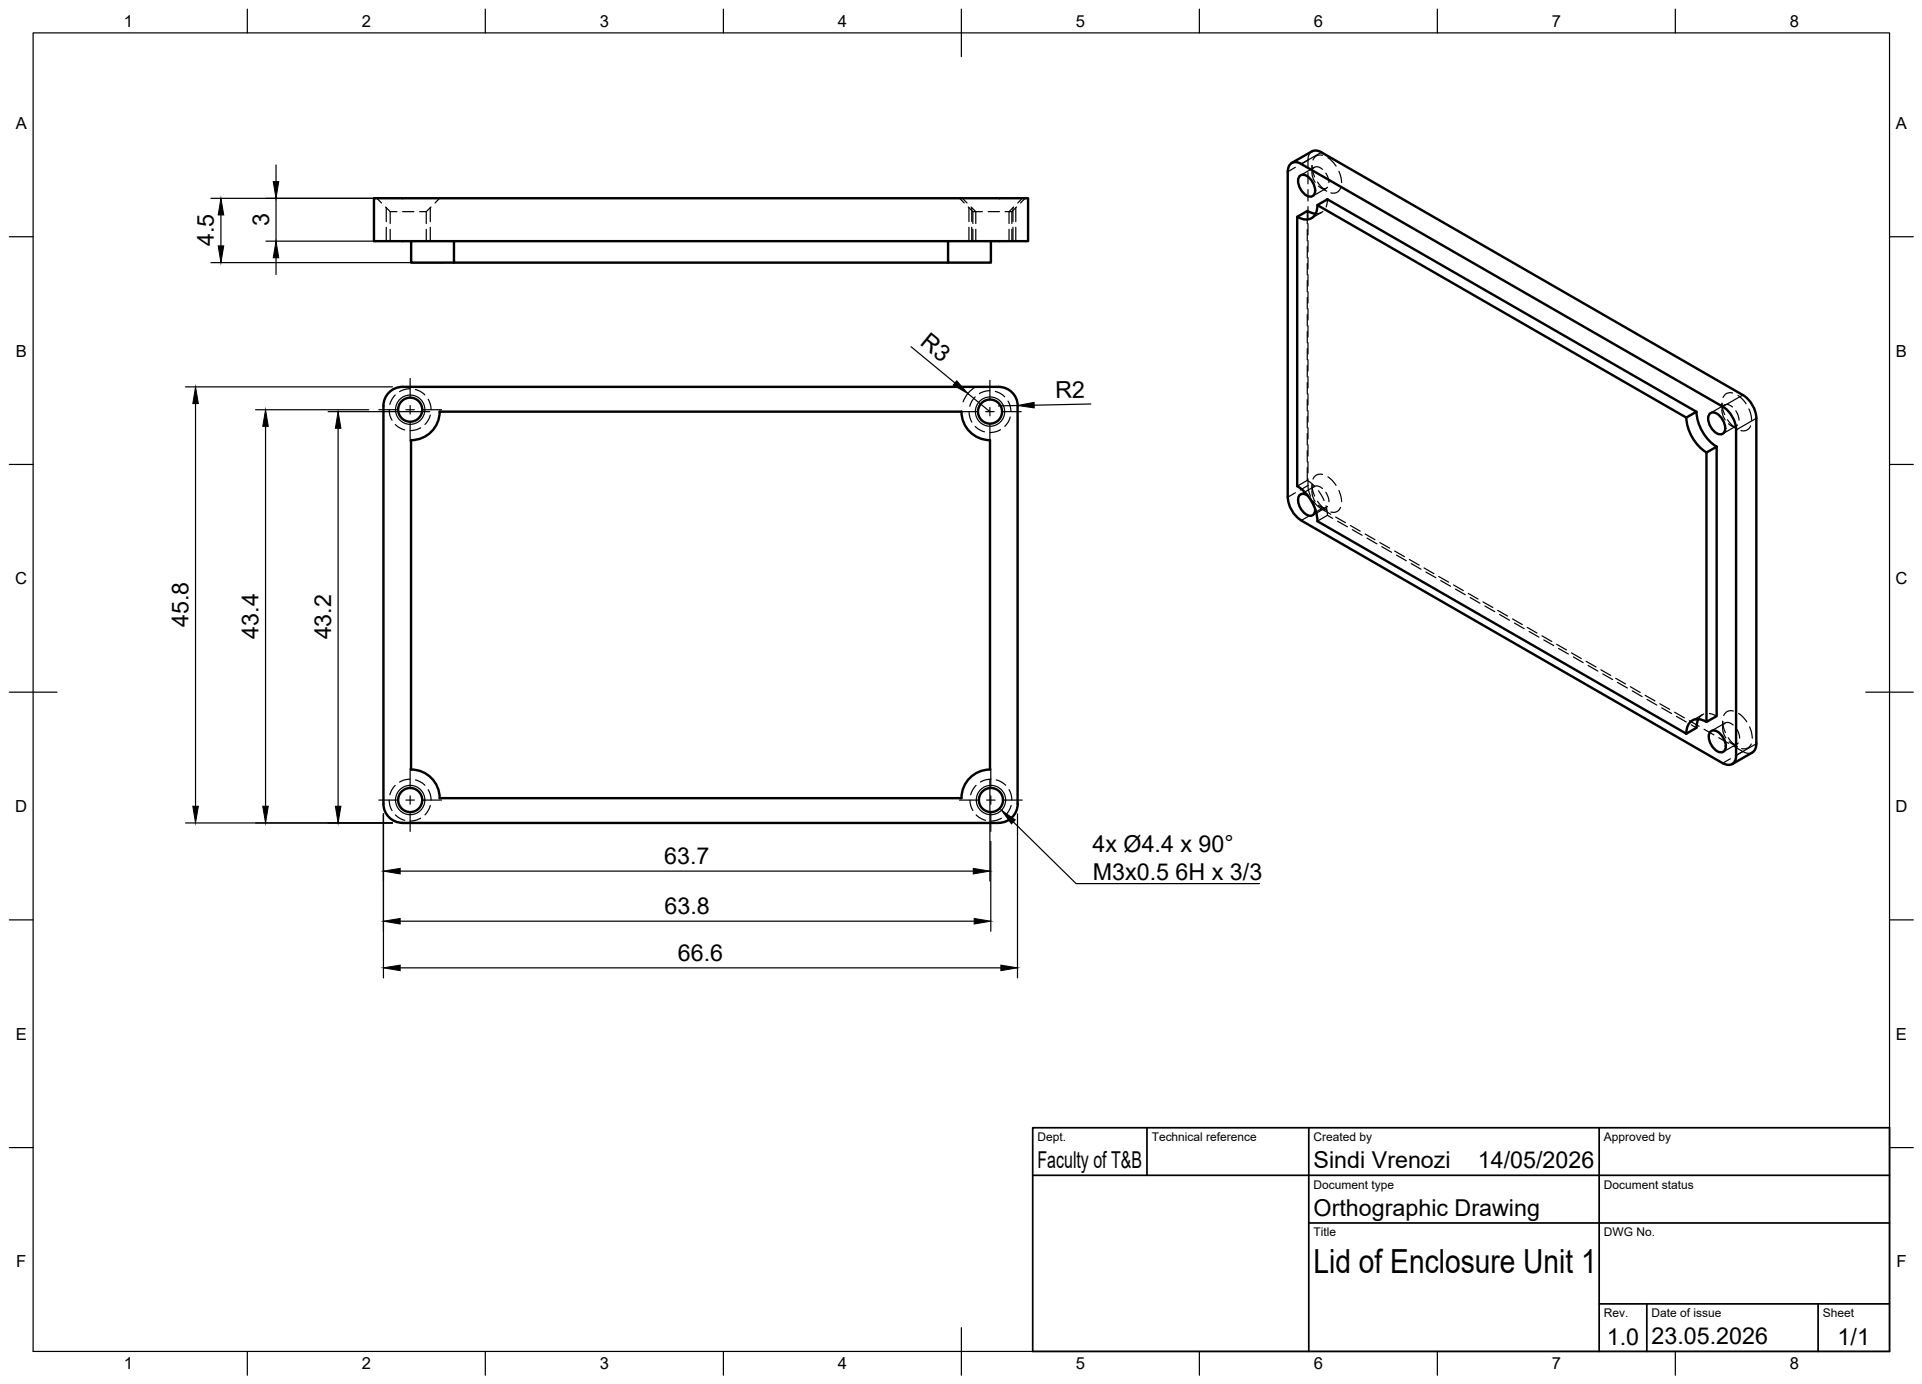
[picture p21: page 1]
Title; DWG No.; Rev.; Date of issue; Sheet

Dept. Faculty of T&B | Technical reference | Created by Sindi Vrenozi 14/05/2026 | Approved by

Document type Orthographic Drawing | Document status

Lid of Enclosure Unit 1

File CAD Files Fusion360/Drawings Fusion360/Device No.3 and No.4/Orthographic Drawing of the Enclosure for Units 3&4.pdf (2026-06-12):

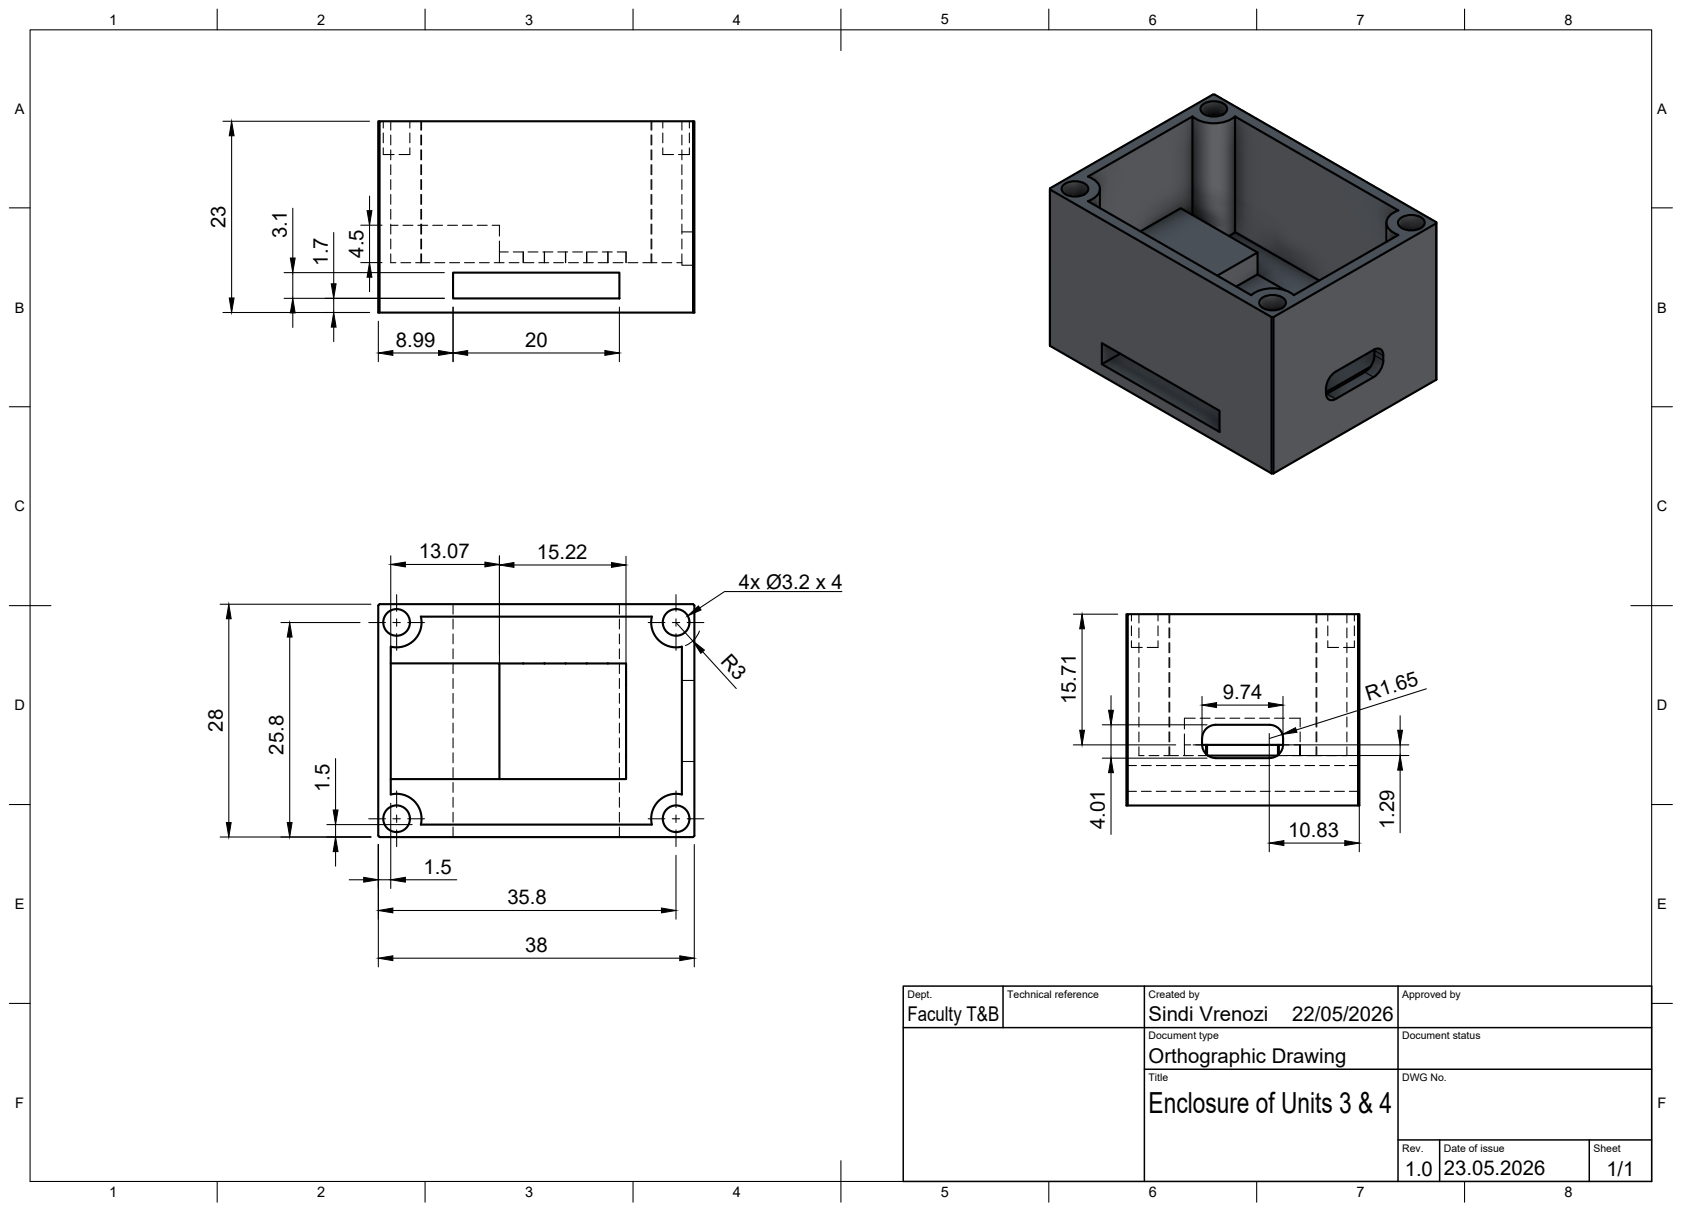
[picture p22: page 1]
Title; DWG No.; Rev.; Date of issue; Sheet

Dept. Faculty T&B | Technical reference | Created by Sindi Vrenozi 22/05/2026 | Approved by

Document type Orthographic Drawing | Document status

Enclosure of Units 3 & 4

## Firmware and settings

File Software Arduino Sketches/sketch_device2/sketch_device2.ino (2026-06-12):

#include <bluefruit.h>
#include "LSM6DS3.h"
#include "Wire.h"
#include <MadgwickAHRS.h>

// ── Change per device the 3 lines below ──────────────────────────────────────────
#define DEVICE_NAME  "SensePlus_2"
#define SERVICE_UUID "23456789-2345-2345-2345-234567890abc"
#define CHAR_UUID    "98765432-5432-5432-5432-dcba98765432"
// ─────────────────────────────────────────────────────────────────────────────

LSM6DS3 imu(I2C_MODE, 0x6A);
Madgwick filter;

BLEService        imuService(SERVICE_UUID);
BLECharacteristic imuChar(CHAR_UUID, CHR_PROPS_NOTIFY, 44);

#define SAMPLE_RATE_HZ  50
#define SAMPLE_INTERVAL (1000 / SAMPLE_RATE_HZ)
unsigned long lastSample = 0;

float gx_bias=0, gy_bias=0, gz_bias=0;
float ax_bias=0, ay_bias=0;
float ax, ay, az, gx, gy, gz;

void calibrateSensors() {
    Serial.println("Keep Flat till calibration...");
    delay(2000);
    float gxs=0, gys=0, gzs=0, axs=0, ays=0;
    for (int i=0; i<500; i++) {
        gxs += imu.readFloatGyroX();
        gys += imu.readFloatGyroY();
        gzs += imu.readFloatGyroZ();
        axs += imu.readFloatAccelX();
        ays += imu.readFloatAccelY();
        delay(4);
    }
    gx_bias=gxs/500; gy_bias=gys/500; gz_bias=gzs/500;
    ax_bias=axs/500; ay_bias=ays/500;
    Serial.println("Calibration done!");
    Serial.print("Gyro bias: ");
    Serial.print(gx_bias); Serial.print(", ");
    Serial.print(gy_bias); Serial.print(", ");
    Serial.println(gz_bias);
}

void connect_callback(uint16_t conn_handle) {
    BLEConnection* conn = Bluefruit.Connection(conn_handle);
    conn->requestMtuExchange(128);
    Serial.println("Connected — MTU exchange requested");
    digitalWrite(LED_GREEN, LOW);
    digitalWrite(LED_BLUE, HIGH);
}

void disconnect_callback(uint16_t conn_handle, uint8_t reason) {
    Serial.println("Disconnected — advertising again");
    digitalWrite(LED_GREEN, HIGH);
    digitalWrite(LED_BLUE, LOW);
}

void setupBLE() {
    Bluefruit.configPrphConn(128, BLE_GAP_EVENT_LENGTH_DEFAULT, 1, 1);
    Bluefruit.begin();
    Bluefruit.setName(DEVICE_NAME);
    Bluefruit.Periph.setConnectCallback(connect_callback);
    Bluefruit.Periph.setDisconnectCallback(disconnect_callback);

    imuService.begin();
    imuChar.setProperties(CHR_PROPS_NOTIFY);
    imuChar.setPermission(SECMODE_OPEN, SECMODE_NO_ACCESS);
    imuChar.setFixedLen(44);
    imuChar.begin();

    Bluefruit.Advertising.addFlags(BLE_GAP_ADV_FLAGS_LE_ONLY_GENERAL_DISC_MODE);
    Bluefruit.Advertising.addTxPower();
    Bluefruit.Advertising.addService(imuService);
    Bluefruit.ScanResponse.addName();
    Bluefruit.Advertising.restartOnDisconnect(true);
    Bluefruit.Advertising.setInterval(32, 244);
    Bluefruit.Advertising.start(0);

    Serial.print("BLE advertising as ");
    Serial.println(DEVICE_NAME);
}

void setup() {
    Serial.begin(115200);
    unsigned long t = millis();
    while (!Serial && millis()-t < 3000);
    delay(500);

    pinMode(LED_RED,   OUTPUT); digitalWrite(LED_RED,   HIGH);
    pinMode(LED_GREEN, OUTPUT); digitalWrite(LED_GREEN, HIGH);
    pinMode(LED_BLUE,  OUTPUT); digitalWrite(LED_BLUE,  HIGH);

    Serial.print("=== "); Serial.print(DEVICE_NAME); Serial.println(" Starting ===");
    Serial.println("Starting IMU...");

    imu.settings.gyroRange       = 2000;
    imu.settings.accelRange      = 8;
    imu.settings.gyroSampleRate  = 416;
    imu.settings.accelSampleRate = 416;

    if (imu.begin() != 0) {
        Serial.println("IMU ERROR!");
        digitalWrite(LED_RED, LOW);
        while(1);
    }
    Serial.println("IMU OK — ±8g accel / ±2000dps gyro");

    calibrateSensors();

    filter.begin(SAMPLE_RATE_HZ);
    filter.beta = 0.033f;

    setupBLE();
    digitalWrite(LED_BLUE, LOW);
}

void loop() {
    unsigned long now = millis();
    if (Bluefruit.connected()) {
        if (now - lastSample >= SAMPLE_INTERVAL) {
            lastSample = now;
            updateIMU();
            sendPacket();
        }
    } else {
        static unsigned long lastPulse = 0;
        if (now - lastPulse > 1000) {
            lastPulse = now;
            digitalWrite(LED_BLUE, LOW);
            delay(100);
            digitalWrite(LED_BLUE, HIGH);
        }
    }
}

void updateIMU() {
    // LSM6DS3 readFloat returns values in g, converting to m/s²
    ax = (imu.readFloatAccelX() - ax_bias) * 9.80665f;
    ay = (imu.readFloatAccelY() - ay_bias) * 9.80665f;
    az = (imu.readFloatAccelZ()) * 9.80665f;

    // Gyro stays in deg/s, no conversion here
    gx = imu.readFloatGyroX() - gx_bias;
    gy = imu.readFloatGyroY() - gy_bias;
    gz = imu.readFloatGyroZ() - gz_bias;

    filter.updateIMU(
        gx * DEG_TO_RAD,
        gy * DEG_TO_RAD,
        gz * DEG_TO_RAD,
        ax / 9.80665f,   // Madgwickfilter needs g units hence conversion from m/s² to g
        ay / 9.80665f,
        az / 9.80665f
    );
}

void sendPacket() {
    uint8_t packet[44];
    uint32_t ts = millis();

    float roll  = filter.getRoll();
    float pitch = filter.getPitch();
    float yaw   = filter.getYaw();

    // Impact detection 
// Now comparing in m/s² 
float mag = sqrt(ax*ax + ay*ay + az*az);
if (abs(mag - 9.81f) > 15.0f) {   // 15 m/s² above gravity = real impact for calibration
    Serial.print("Impact");
    Serial.print(mag);
    Serial.println(" m/s²");
}

    memcpy(packet+0,  &ts,    4);
    memcpy(packet+4,  &ax,    4);
    memcpy(packet+8,  &ay,    4);
    memcpy(packet+12, &az,    4);
    memcpy(packet+16, &gx,    4);
    memcpy(packet+20, &gy,    4);
    memcpy(packet+24, &gz,    4);
    memcpy(packet+28, &roll,  4);
    memcpy(packet+32, &pitch, 4);
    memcpy(packet+36, &yaw,   4);
    float zero = 0;
    memcpy(packet+40, &zero,  4);

    imuChar.notify(packet, 44);

    // Debug output
    Serial.print("ax="); Serial.print(ax,3);
    Serial.print(" ay="); Serial.print(ay,3);
    Serial.print(" az="); Serial.print(az,3);
    Serial.print(" | gx="); Serial.print(gx,2);
    Serial.print(" gy="); Serial.print(gy,2);
    Serial.print(" gz="); Serial.print(gz,2);
    Serial.print(" | R="); Serial.print(roll,1);
    Serial.print(" P="); Serial.print(pitch,1);
    Serial.print(" Y="); Serial.println(yaw,1);
}

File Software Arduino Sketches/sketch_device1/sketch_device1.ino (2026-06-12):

#include <Wire.h>
#include <Adafruit_Sensor.h>
#include <Adafruit_BNO055.h>
#include <utility/imumaths.h>
#include <ArduinoBLE.h>

// ── BLE ───────────────────────────────────────────────────────────────────────
BLEService imuService("12345678-1234-1234-1234-123456789abc");
BLECharacteristic imuChar(
    "87654321-4321-4321-4321-cba987654321",
    BLENotify,
    44,
    true
);

// ── IMU ───────────────────────────────────────────────────────────────────────
Adafruit_BNO055 bno = Adafruit_BNO055(55, 0x28, &Wire);

// ── Timing ───────────────────────────────────────────────────────────────────
#define SAMPLE_RATE_HZ  50
#define SAMPLE_INTERVAL (1000 / SAMPLE_RATE_HZ)   // 20ms
unsigned long lastSample = 0;

// ── Sleep/Wake ────────────────────────────────────────────────────────────────
void goToSleep() {
    bno.enterSuspendMode();
    digitalWrite(LEDG, HIGH);
    digitalWrite(LEDR, HIGH);
    digitalWrite(LEDB, HIGH);
    Serial.println("Sleeping — waiting for BLE connection...");
}

void wakeUp() {
    bno.enterNormalMode();
    delay(500);
    Serial.println("Waking up — BNO055 resuming...");
}

// ── Setup ─────────────────────────────────────────────────────────────────────
void setup() {
    Serial.begin(115200);
    delay(2000);

    pinMode(LEDR, OUTPUT); digitalWrite(LEDR, HIGH);
    pinMode(LEDG, OUTPUT); digitalWrite(LEDG, HIGH);
    pinMode(LEDB, OUTPUT); digitalWrite(LEDB, HIGH);

    Serial.println("=== WearableBLE Starting ===");
    Serial.println("Initialising BNO055...");

    if (!bno.begin()) {
        Serial.println("BNO055 not detected — check wiring!");
        digitalWrite(LEDR, LOW);
        while (1);
    }
    bno.setExtCrystalUse(true);
    Serial.println("BNO055 ready!");

    Serial.println("Initialising BLE...");
    if (!BLE.begin()) {
        Serial.println("BLE failed!");
        digitalWrite(LEDR, LOW);
        while (1);
    }

    BLE.setLocalName("WearableBLE");
    BLE.setAdvertisedService(imuService);
    imuService.addCharacteristic(imuChar);
    BLE.addService(imuService);
    BLE.advertise();

    Serial.println("Advertising as Device 1 — ready!");
    digitalWrite(LEDB, LOW);   // blue = advertising
}

// ── Loop ──────────────────────────────────────────────────────────────────────
void loop() {
    BLEDevice central = BLE.central();

    if (central) {
        wakeUp();
        Serial.print("Connected: ");
        Serial.println(central.address());
        digitalWrite(LEDG, LOW);    // green = connected
        digitalWrite(LEDB, HIGH);

        while (central.connected()) {
            unsigned long now = millis();
            if (now - lastSample >= SAMPLE_INTERVAL) {
                lastSample = now;
                sendImuPacket();
            }
        }

        Serial.println("Disconnected");
        digitalWrite(LEDG, HIGH);
        goToSleep();

    } else {
        // Slow pulse blue — sleeping/advertising
        static unsigned long lastPulse = 0;
        unsigned long now = millis();
        if (now - lastPulse > 1000) {
            lastPulse = now;
            digitalWrite(LEDB, LOW);
            delay(100);
            digitalWrite(LEDB, HIGH);
        }
    }
}

// ── Send Packet ───────────────────────────────────────────────────────────────
// 44 bytes: timestamp(4) + accel xyz(12) + gyro xyz(12) + quat wxyz(16)
void sendImuPacket() {
    imu::Vector<3> accel = bno.getVector(Adafruit_BNO055::VECTOR_ACCELEROMETER);
    imu::Vector<3> gyro  = bno.getVector(Adafruit_BNO055::VECTOR_GYROSCOPE);
    imu::Quaternion quat = bno.getQuat();

    uint8_t packet[44];
    uint32_t ts = millis();

    float ax = (float)accel.x();
    float ay = (float)accel.y();
    float az = (float)accel.z();
    float gx = (float)gyro.x();
    float gy = (float)gyro.y();
    float gz = (float)gyro.z();
    float qw = (float)quat.w();
    float qx = (float)quat.x();
    float qy = (float)quat.y();
    float qz = (float)quat.z();

    memcpy(packet+0,  &ts, 4);
    memcpy(packet+4,  &ax, 4);
    memcpy(packet+8,  &ay, 4);
    memcpy(packet+12, &az, 4);
    memcpy(packet+16, &gx, 4);
    memcpy(packet+20, &gy, 4);
    memcpy(packet+24, &gz, 4);
    memcpy(packet+28, &qw, 4);
    memcpy(packet+32, &qx, 4);
    memcpy(packet+36, &qy, 4);
    memcpy(packet+40, &qz, 4);

    imuChar.writeValue(packet, 44);

    // Debug
    Serial.print("ax="); Serial.print(ax,3);
    Serial.print(" ay="); Serial.print(ay,3);
    Serial.print(" az="); Serial.print(az,3);
    Serial.print(" | gx="); Serial.print(gx,2);
    Serial.print(" gy="); Serial.print(gy,2);
    Serial.print(" gz="); Serial.print(gz,2);
    Serial.print(" | qw="); Serial.print(qw,3);
    Serial.print(" qx="); Serial.print(qx,3);
    Serial.print(" qy="); Serial.print(qy,3);
    Serial.print(" qz="); Serial.println(qz,3);
}

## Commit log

2026-06-12 Adds initial files & readme
    [Adafruit_BNO055_AP214.step, Assembly Drawing and Parts List Unit 1.dwg, Assembly Drawing and Parts List Unit 2.dwg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]
2026-06-12 Add machinle learnign folder content + training session data
    [1a.csv, 1b.csv, 1c.csv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]
